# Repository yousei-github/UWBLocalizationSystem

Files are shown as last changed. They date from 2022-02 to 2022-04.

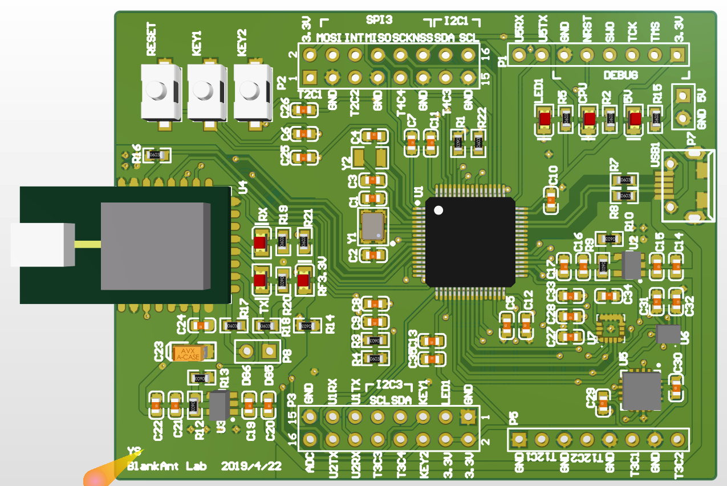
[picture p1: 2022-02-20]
Hardware/picture.png

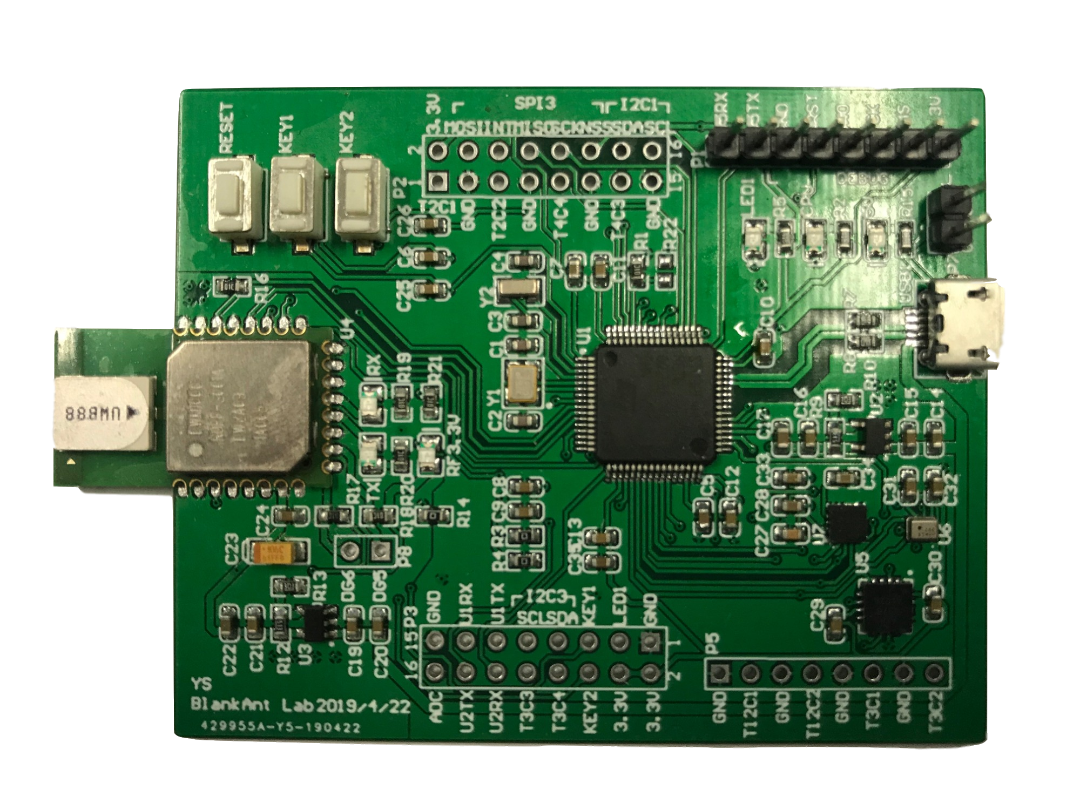
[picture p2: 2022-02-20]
Hardware/real_board.png

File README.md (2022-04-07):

# UWBLocalizationSystem
Designed a localization system based on ultra-wideband technologies (i.e., DWM1000) for the graduation project, which can achieve decimeter-level positioning accuracy using four anchors to navigate the subject (e.g., drone) in the indoor environment. 

## How to compile and execute this project
Please use keil to program this project, such as compile, debug.

Link: https://www.keil.com/

## About the hardware
Please use altium designer to open the hardware design files.

Link: https://www.altium.com/

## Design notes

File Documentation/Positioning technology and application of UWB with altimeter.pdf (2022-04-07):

学号

年级

# 本科毕业论文

# 结合高度计的 UWB 的空间定位技术与应用

专 | 业 | 电子信息工程
姓 | 名 | 杨晟
指导教师 | 李东新 教授

## 评 阅 人

2019 年 5 月

## 中国 南京

## BACHELOR'S DEGREE THESIS OF HOHAI UNIVERSITY

## Positioning technology and application of UWB with altimeter

College | ：College of Computer and Information
Subject | ：Electronic Information Engineering
Name | ：Sheng Yang

Directed by ：Dongxin Li Professor

## NANJING CHINA

# 郑 重 声 明

本人呈交的毕业论文，是在导师的指导下，独立进行研究工作所 取得的成果，所有数据、图片资料真实可靠。尽我所知，除文中已经 注明引用的内容外，本设计（论文）的研究成果不包含他人享有著作 权的内容。对本设计（论文）所涉及的研究工作做出贡献的其他个人 和集体，均已在文中以明确的方式标明。本设计（论文）的知识产权 归属于培养单位。

本人签名： | 日期：

摘 要

无线通信正在成长为我们日常生活的重要组成部分。 卫星通信，蜂窝网络，

无线局域网（WLAN）和无线传感器网络（WSN）是我们每天使用的这些无线技术。

超宽带（UWB）是一种具有大带宽的有前途的技术。 UWB 的这种独特特性使其成为

各种通信，测距和雷达的有吸引力的技术。 本文将重点关注基于 UWB 的精确定位

方面。 由于锚的位置必须手动确认，这有点不方便并且可能带来巨大的错误。 因

此，我使用高度计传感器来帮助定位所有锚点在 z 轴上的位置。 进行实验以比较

使用高度计和不使用高度计的性能

关键词：无线网络；超宽带定位；定位技术；测高计

## ABSTRACT

Wireless communications are growing up to be an essential part of our everyday

lives. Satellite communications, cellular networks, wireless local area networks

(WLANs), and wireless sensor networks (WSNs) are these wireless technologies that

we use every day. Ultra-wideband (UWB) is a promising technology which has large

bandwidths. Such unique trait of UWB turns it into an attractive technology for diverse

communications, ranging, and radar. This paper would focus on the aspect of precise

localization based on UWB. Since the positions of anchors must be confirmed manually,

which is a little inconvenient and may bring enormous error. Therefore, I use the

altimeter sensor to help locate all anchors& position in z-axis. An experiment is

conducted to compare the performance of using altimeter and without it.

Key words: wireless networks；Ultra-wideband；localization； altimeter

## Contents

## Chapter 1 Introduction

1.1 Problem and Research Significance

As wireless devices are growing up to be more and more integrated into

our everyday lives, they are also getting more and more intelligent. In

the book[1]

, it says wireless devices are becoming more context aware, which

is described as the ability of the mobile device to be aware of the its

surrounding environment. Another definition means that if a system is

context aware, it will offer relevant information and services to the user,

which depends on the user’s aims or tasks. Usually those services are based

on the context information such as time, location, temperature, speed,

orientation, biometrics, audio/video recordings, etc.

Among this various information above, location is the main focus in

my paper and is probably the most prevalent factor which depicts a specific

situation. For example in cellular system, location information can be

utilized to Emergency services (911), resource management, and intelligent

logistic systems. In hospitals location of the patients, injured tourists

on mountains, or firefighters inside a building are some examples showing

how location information work in an emergency circumstance. As an office

worker, it would be convenient to find the closest printer while knowing

your position in a wireless network. A customer can receive advertisements

based on location in a supermarket. Such intelligent wireless network

application with location information would make our live much comfortable

and easier.

Real Time Location Systems (RTLS) describes a class of systems that

provide information in real-time about the location of objects, animals,

people or just about anything you care about. The most typical example of

a RTLS is Global Positioning Systems (GPS) developed by the US Department of Defense. It uses the time difference of arrival (TDOA) information from

four or more of 24 satellites around the world to estimate target’s outdoor

position with an accuracy between 1 and 5 m; but it performs poorly for

the indoors environment since walls block GPS signals. Indoor localization

system may need other technology to locate target.

In general, there exists four fundamental signaling scheme that can

be used for a localization system. Radio frequency (RF) maybe the most

commonly used signaling scheme for localization purposes since RF signals

can penetrate through obstacles and propagate to long distances. Cheng

Chen[2]

employed Wi-Fi, odometer and IMU (Inertial measurement unit) fusion

for indoor positioning, and get good results. Infrared signals are low power

consuming and cheap; however, they cannot penetrate through obstructions

(contrast to RF), and are vulnerable against sunlight. Optical signals also

require line-of-sight (LOS) conditions, affected by sunlight, but are low

power consuming. They provide high accuracy and are normally more

appropriate for short ranges (like about 10 m). Liu’s Research[3]

achieved

sub-meter accuracy with fluorescent light communication system. Finally,

an inexpensive signaling scheme is ultrasound signals, which have high

accuracy in the short range. An advantage of acoustic signals is that the

sound travels slowly. Therefore, the localization system doesn’t require

high clocks to timestamp messages, and can be achieved inexpensively in

LOS conditions. With acoustic sensors Qiu[4]

also realize a sub-meter

localization system. However, ultrasound signals cannot work well in

non-line-of-sight (NLOS) scenario.

Ultra-Wideband (UWB) is a RF technology which can achieve

centimeter-level positioning and a range of up to 300 meters. Many

researches have been done using UWB technology, such as Tiemann’s Unmanned

Aerial Vehicle (UAV) navigation[5]

and Shi’s formation flight system[6]

, and

they all get great results. My research would also base on RF signals with

UWB technology to achieve a RTLS.

There are numerous properties of radio waves used to achieve radio

positioning. For instance, time-of-arrival (TOA), time difference of

arrival (TDOA), angle of arrival (AOA), and received signal strength (RSS).

Various methods have been developed over these years to measure radio waves

like time-of-flight (TOF), signal phase, signal strength and angle of

arrival. In most cases, the localization system based on determining the

TOF, which is a similar concept of the TOA, can realize high accuracy. A

fundamental localization method is trilateration. In this case, at least

three serving reference node (RN) are required for two-dimensional (2-D)

localization, and at least four RNs are required for three-dimensional (3-D)

localization. In a localization system, the communication node is often

classified as mobile station and base station. Moreover, mobile station

may equal to tag and base station is often referred to as anchor. In the

case of trilateration, if the absolute location of the anchors is known

in 2D or 3D space then the absolute location of the tags is also known.

Thus, measuring the absolute location of the anchors improperly may bring

enormous error. This paper uses the altimeter sensor to help mitigate all

anchors& position error in z-axis.

### 1.2 Main Design of This System

UWB is an excellent RF technology for high accuracy localization in

short (less than 100 m) to medium (up to 2000 m) distances due to its high

time resolution and inexpensive circuitry. There are already a number of

UWB ranging and positioning devices in the market. Being compliant with

IEEE802.15.4 standard, the Sapphire DART system from Multispectral

Solutions, Inc, Ubisense real-time location system and DecaWave’s DW1000[7]

are all available UWB localization products. An ideal localization system

should fit in all kinds of application, such as accuracy, cost, range, and

complexity. In order to reach these goals, a positioning node is designed with DecaWave’s DWM1000 module[8]

Many RTLS based on UWB technology like Tiemann’s and Shi’s need to

calculate or confirm all anchors’ absolute position manually, which

usually results in each anchor mounts on a regular shelf or framework (like

cuboid and so on). But when employing their system into a more bigger space,

it might become inappropriate as well as deteriorate its accuracy. To

mitigate this drawback, a compensation approach is present and will be

evaluated by taking advantage of altimeter.

## Chapter 2 System Theory Analysis

2.1 Ultra-Wideband

Guglielmo Marconi’s spark gap radio transmitters send UWB signals

across the Atlantic Ocean in 1901, but the precise investigation of UWB

systems was conducted by the studies on impulse response characterization

of microwave networks in the 1960s. Early names of UWB technology include

baseband, carrier-free, non-sinusoidal and impulse. The US Department of

Defense named the term UWB in the late 1980s. A UWB signal is characterized

by its very large bandwidth compared to the conventional narrowband systems,

which means a signal is called UWB if it has an absolute bandwidth of at

least 500 MHz, or its fractional bandwidth is larger than 0.2. The absolute

bandwidth is calculated as the difference between the upper frequency fH

of the −10 dB emission point and the lower frequency fL of the −10 dB

emission point:

| B = fH − fL

(2.1)

which is also called −10 dB bandwidth. Besides, the fractional bandwidth

is defined as

| Bfrac = B fc
(2.2)

where fc is the center frequency and is given by
| fc = fH + fL
| 2

(2.3)

the fractional bandwidth Bfrac in (2.2) can be written as from (2.1) and

(2.3)

| Bfrac = 2(fH − fL ) fH + fL
(2.4)

In accordance with the definition of the US FCC[9]

| , a UWB system with fc that

is larger than 2.5 GHz must have an absolute bandwidth larger than 500

MHz, and then a UWB system with fc which is less than 2.5 GHz must have

a fractional bandwidth larger than 0.2 as showing in Fig. 2.1

Fig. 2. 1 A UWB signal have an absolute bandwidth B ≥ 500 MHz or a fractional bandwidth Bfrac > 0. 2

Because of its large bandwidth, the UWB system has very short duration

waveforms, which usually is several nanoseconds. Ordinarily, the UWB system

transmits ultra-short pulses with a low duty cycle. In this case, the ratio

between the pulse transmission moment and the average time between two

consecutive transmission frames is normally kept small, which commonly

bring an advantage that saving power and energy. Nevertheless, it is

reasonable to keep both low duty cycle instant and continuous transmission

frames.

In a UWB system, numerous pulses are transmitted per information symbol

and information is usually transferred by the positions or the polarities

of the pulses, which was shown in Fig. 2.2. Each pulse occupies in an interval

called a “frame”, and the positions of the pulses in the frames are

determined by a time-hopping (TH) code so that reduce the probability of

collisions with pulses from other UWM system. In Fig. 2.2, three information

have been transmitted, and each bit is composed of two pulses or two frames.

The TH code of the first bit is {2,1}, which implied that in the first frame

the pulse is shifted by 2Tc seconds and the second one is shifted by Tc

seconds, where Tc refers to the chip interval.

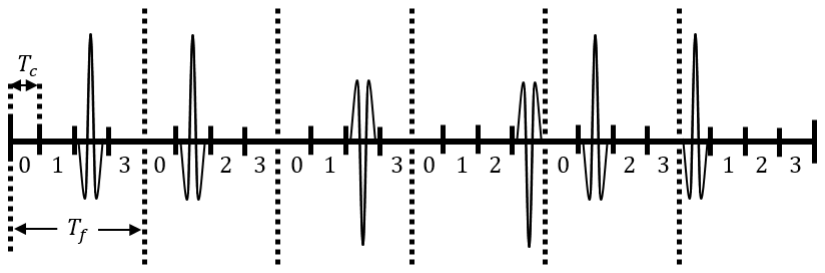
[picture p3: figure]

Fig. 2. 2 A UWB signal whose positions of the pulses in different frames are determined by a TH code, which is {2, 1, 2,3, 1, 0} in this example

2.2 Basic Positioning Methods

There are a variety of different methods of position determination in

RTLS using radio signals but they effectively devolve into two basic types

of scheme:

1) Those based on radio signal strength – commonly referred to as Received

Signal Strength Indication (RSSI/RSS) scheme;

2) Those based on the Time of flight – where the time the radio signal

takes traveling between transmitter and receiver is measured and the

distance can be calculated by using the speed of light. For example, Time

of Arrival, Time Difference of Arrival and Phase difference of Arrival (PDOA)

are three main methods based on Time of flight.

2.2.1 Received signal strength

In this situation, we need to measure the signal strength of the arriving

radio signal at the receiver. Given the power at which the signal was

transmitted from the transmitter, the propagation characteristics of this

radio signal in air and with some a preferred knowledge of the environment,

then it is possible to calculate approximately where the transmission

derived based on how attenuated it is at the receiver.

However, since the RSS usually has a specific (static) distribution

pattern over the localization area, if other objects enter or move in that

area (like people or animals) the distribution pattern would change

perceptibly. This change may greatly worsen the reliability of the

localization system.

On the other hand, such characteristic also has some advantages. In the

field of detection for intrusions or burglaries, positioning needs to be

achieved without performing any communications between the target

(intruder) and the base stations. Using the RSS method and analyzing for

any change in an otherwise static signal pattern, possible intrusions can

be detected.

2.2.2 Time of Arrival

Working on the basis of determining the time it spends for a radio signal

on transmitting from a transmitter to a receiver, the distance between the

transmitter and the receiver can be determined as long as this time is

calculated precisely, given that the speed of propagation of radio waves

in air is known.

Applying the Time of Arrival method to achieve a RTLS, the distance

between the tags and several anchors in known locations must be measured.

In Fig. 2.3 we can see that anchor P1 measures the distance between itself

and the tag B as r1. This locates the tag B on a circle of radius r1 from

the anchor P1. It is the same case that P2 measures the distance with the

tag B as r2 and P3 gets the distance as r3. According to a fundamental

localization method, which is trilateration, calculating the point of

intersection between these three circles could figure out the position of

tag B. The prior condition of this method is the absolute location of the

anchors required to be known.

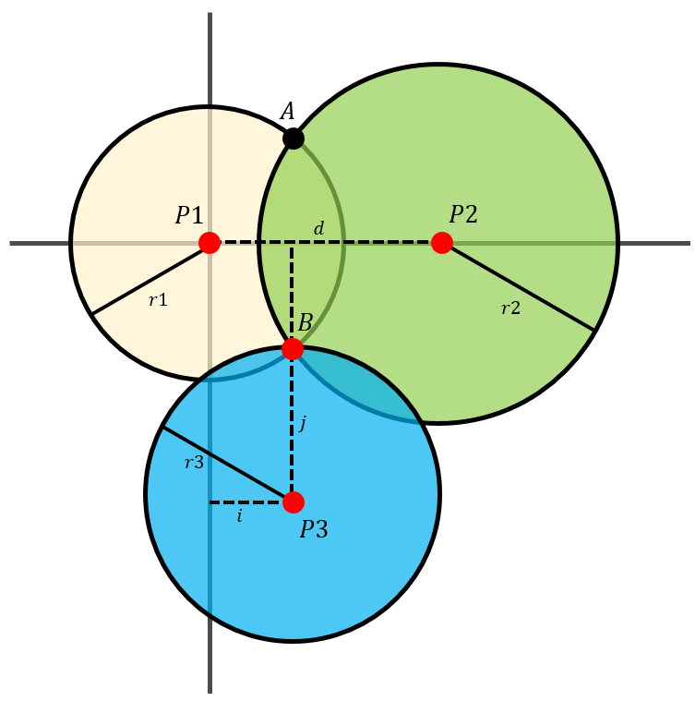
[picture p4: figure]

Fig. 2. 3 Time of Arrival method

2.2.3 Time Difference of Arrival

The similar requirement of TDOA as TOA is that three or more anchors

are utilised in known locations in the environment to locate the positions

of the tags. But each of these anchors is time synchronized to the others.

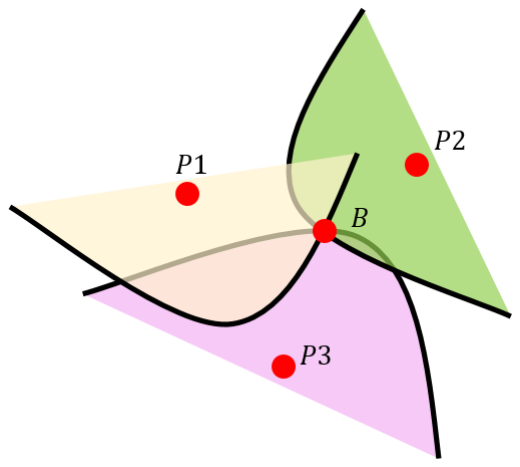
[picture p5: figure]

Fig. 2. 4 Time Difference of Arrival method

As shown in Fig. 2.4 the tag B transmits a message that is received by

all the anchors (P1, P2 and P3). Due to radio wave propagates in air at a

constant speed, relying on the position of the tag B, the message will reach

at some of the anchors before others. Each anchor will record the time of

arrive of this message. Because all three anchors are time synchronized, the difference of the time of arrive among all anchors could estimate the

position of the tag B.

Obviously, the most difficult issue in this method is how to synchronize

all anchors in time. Any error produced in the synchronization process will

directly affect the accuracy of this RTLS. It is because a UWB pulse duration

is usually less than 1 ns, you can think that 1 ns = 30 cm, which means that

the synchronization error must to be controlled within the sub-nanosecond

level to realize high accuracy.

2.2.4 Phase Difference of Arrival

The conception of Phase Difference of Arrival is to calculate the

distance between an anchor and a tag as well as the x, y location of this

tag relative to the corresponding anchor.

This method generally uses an array of antennas in the anchor. The time

of arrive at different antennas will be measured and then the difference

for all TOAs is compared. Showing in Fig. 2.5.

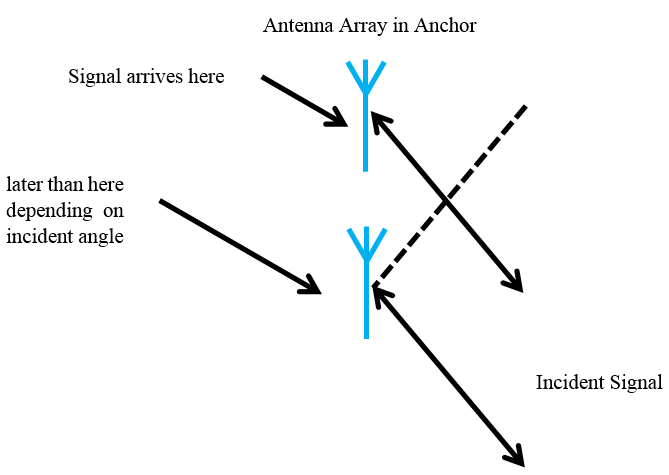
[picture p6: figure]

Fig. 2. 5 Phase Difference of Arrival antenna array

If the tag is coincidentally perpendicular to the antennas in the array,

the incident signal would arrive at all the antennas at the same time, so

there would be no difference in TOA. In most cases, the tag is at some angle

to the array so that the incident signal will arrive at one antenna in the

array first and then next one and so on. It is possible to derive the location

of this tag with precise measurement of Phase Difference of Arrival. On the other hand, increasing the number of antennas per anchor would

apparently adds cost to the RSTL.

2.3 Position Determination Algorithm

Most of common position determination algorithms are based on the

measurement of the TOA of the radio signal, since it can provide the most

accurate position determination. Due to this measurement is the arrival

time at the receiver rather than the Time of Flight, the available

measurement data are pseudo-ranges (range plus an unknown offset), compared

to ranges, there are a number of position determination algorithms used

to process these pseudo-ranges data in a classical localization system

where several fixed anchors are used to determine the location of a tag.

2.3.1 Noniterative Position Determination

Focusing on noniterative position determination methods, the raw

measured data are processed using analytical formulas to calculate the

position of a tag directly. Such algorithms are trilateration, spherical

interpolation (SI), quasi-least squares (QLS), and linear correction

least-squares (LC-LS). Although these methods can definitely get a position

fix, the analytical equations would be computationally intensive. Thus they

might not be appropriate for simple localization system with several nodes

and limited computational capability.

1) Trilateration Position Calculation

In Fig. 2.3 showing a simple example of how to calculate the location of

the tag with the distance measurements from three anchors in a 2D

environment. The tag can communicate with three anchors and its position

is located on each distance circle with the corresponding anchor location

as the center and the distance as the radius. Generally, two distance

circles intersect at two points, which would produce two solutions for the

position estimate of the tag. Therefore, a third anchor is needed to produce

a third distance circle in order to solve this ambiguity of the two solutions.

In general, these circles will not intercross at one point, thus, other

methods are required to calculate the position. There is a straightforward

way that to compute the distance between the third anchor and each of the

two solutions. The two result distances are then compared with the third

distance circle each other. The one which better matches with third anchor

will be the solution, which can be seen that the tag and three anchors cannot

lie in a straight line to calculate a unique position estimate. In Fig. 2.6,

a 3D position estimation is shown.

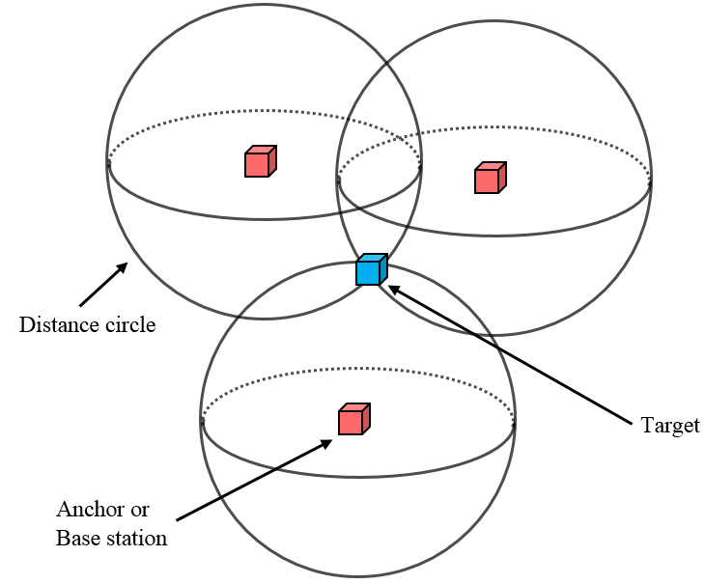
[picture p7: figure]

Fig. 2. 6 Position estimation in 3D environment

Suppose that there are four anchors with known locations given by

(xi
, yi

, zi

), 1 ≤ i ≤ 4, and that the unknown location of the target is denoted

by (x, y, z). The distance measurement equations are defined as

d̂
i = di + εi
i = 1, 2, 3, 4 | (2.5)

where εi is the distance measurement error and

di = √(x − xi
)

2 + (y − yi
)

2 + (z − zi
)
2 | (2.6)

Since there are three unknown location parameters, let us first use three

distance measurements, say d̂

1, d̂

2 and d̂
3, to determine the location. Define

ζi,1 = xi

2 + yi

2 + zi

2 − (x1
2 + y1

2 + z1

2
)

xi,j = xi − xj

yi,j = yi − yj | (2.7)

zi,j = zi − zj

f1,i =

1
2

{(d̂
1

2
− d̂
i

2
) + ζi,1}

Also define

κ1 =

x2,1z3,1 − x3,1z2,1

x3,1y2,1 − x2,1y3,1

κ2 =

x3,1f1,2 − x2,1f1,3

x3,1y2,1 − x2,1y3,1

κ3 =

y3,1z2,1 − y2,1z3,1

x3,1y2,1 − x2,1y3,1

κ4 =

y2,1f1,3 − y3,1f1,2

x3,1y2,1 − x2,1y3,1

(2.8)

Then, with some mathematical manipulations, it can be shown that the

estimate of the z-coordinate of the position is

ẑ=

ℎ2
ℎ1

± √(
ℎ2
ℎ1

)

2
−

ℎ3
ℎ1

(2.9)

Where

ℎ1 = κ1

2 + κ3

2 + 1

ℎ2 = κ1

(y1 − κ2

) + κ3

(x1 − κ4

) + z1

ℎ3 = (x1 − κ4

)

2 + (y1 − κ2
)

2 + z1

2 − d̂
1

2

(2.10)

Accordingly, the estimates of the x-coordinate and y-coordinate can be

obtained as

x̂ = κ3ẑ+ κ4

ŷ = κ1ẑ+ κ2

(2.11)

Clearly, there are two solutions, but only one of them is the desired one.

The ambiguity can be resolved by making use of the measurement at the fourth

anchor. Specifically, the residuals of the two location estimation

solutions are calculated by

v1 = [√(x4 − x̂
(1))
2 + (y4 − ŷ

(1))
2(z4 − ẑ

(1))

2 − d̂

4]

2

v2 = [√(x4 − x̂
(2))
2 + (y4 − ŷ

(2))
2(z4 − ẑ

(2))

2 − d̂

4]

2 | (2.12)

If v1 > v2, then the second solution (x̂

(2)
, ŷ

(2)
, ẑ

(2)
) is chosen. Otherwise,

the first solution (x̂

(1)
, ŷ

(1)
, ẑ

(1)
) is selected. To make the residual-based

judgment as reliable as possible, the fourth anchor should not be on the

same plane formed by the other three anchors.

2) Least-Squares Method based on an Intermediate Variable

When the system is overdetermined, which means the number of independent

equations is greater than the number of unknown parameters, the

Least-Squares (LS) method can be applied to make use of the redundant

measurements to obtain improved location estimates.

Consider a network in which there are N anchors whose locations are

known and denoted by (xi
, yi

, zi

), i = 1, 2, ⋯ , N. The unknown location of the

target is defined as (x, y, z). When a distance measurement is made at each

anchor, there are N measurement equations:

d̂
i = di + vi
i = 1, 2, ⋯ , N | (2.13)

Where

di = √(xi − x)
2 + (yi − y)

2 + (zi − z)

2 | (2.14)

and vi is the measurement error.

Linearization of the distance measurement equations can be realized by

introducing a new variable. Specifically, squaring both sides of (2.13)

produces

−(2xix + 2yiy + 2ziz) + (x

2 + y

2 + z

2

) = (d̂
i − vi)

2
− (xi

2 + yi

2 + zi

2
)
| (2.15)

Then, by defining

R = √x
2 + y

2 + z

2

Ri = √xi
2 + yi 2 + zi
2 | (2.16)
(2.15) becomes

−(2xix + 2yiy + 2ziz) + R

2 = d̂
i

2 − Ri

2 + vi

2 − 2d̂
ivi

(2.17)

which can be written in a compact form as

h = Gθ + v | (2.18)

Where
θ = [x y z R
2]

T

h =
[

d̂
1

2 − R1

2
d̂
2

2 − R2

2
⋮
d̂
N

2 − RN

2

]

G = [

−2x1 | −2y1
−2x2 | −2y2
−2z1 | 1
−2z2 | 1
⋮ | ⋮
−2xN | −2yN
⋮ | ⋮
−2zN | 1

]

v = [−v1

2 + 2d̂
1v1 −v2

2 + 2d̂
2v2 ⋯ −vN

2 + 2d̂
NvN

]

T

(2.19)

The LS solution of (2.18) is

θ̂ = (G
TWG)

−1G

TWh | (2.20)

where W = cov⁻¹
(v) is the weighting matrix which is set to be the inverse

of the covariance matrix of v for Gaussian noise. In the case of unknown

statistics of the error vector v, W may be set at a diagonal matrix with

the SNRs determined by receivers as the diagonal elements, or simply set

at an identity matrix.

2.3.2 Iterative Position Determination

In this case, iterative methods are used to solve the nonlinear

equations which describe the position determination problem. For example,

there are Taylor series least squares (TS-LS) method, the iterative

optimization method and the maximum likelihood (ML) method and Kalman

filter iterative method. Commonly, these iterative methods need an initial

‘guess’ of the position, but in some situation, especially when large

measurement errors are present these algorithms may not converge.

Nevertheless, in the localization system while continuous periodic updates

are running, the previous position can be used as the initial position, which normally approaches to a rapid convergence of position determination

without large computation contrasting to the noniterative methods.

2.4 Indoor Height Determination

In order to measure the height between the target object and reference

plain, there are several kinds of commercial sensors could be used. They

may be classified as three types: laser, ultrasonic and barometer. The first

two types both can achieve high accuracy and stability, but they all need

the line of sight environment, which means that if height measurement is

required, these sensors must be installed on the bottom of the target object

and should be toward to the reference plain (like ground), and the line

between them cannot be block by other obstacles. As a result, it is

inconvenient to utilize the laser or ultrasonic sensors to measure height.

However, the barometer (or altimeter) can determine the height without the

line of sight requirement.

2.4.1 Atmospheric pressure measurement

The atmospheric pressure is the weight exerted by the overhead

atmosphere on a unit area of surface. It can be measured with a mercury

barometer, as shown in Fig. 2.7.

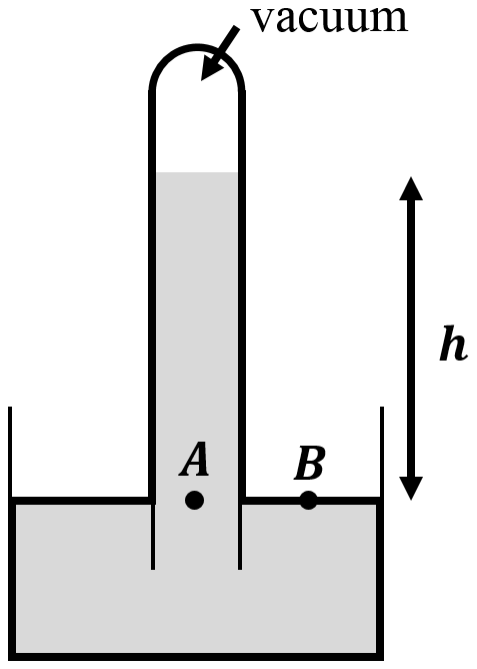
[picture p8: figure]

Fig. 2. 7 Mercury barometer

There is a long glass tube that is full of mercury inverted over a pool

of mercury. According to some physical knowledge, it is well known that

the pressure PA at point A is equal to the pressure PB at point B and the

equilibrium equation can be represented as:

PA = ρHg gℎ | (2.21)
where ρHg = 13.6 g cm⁻³ is the density of mercury and g = 9.8 m s | −2 is the

acceleration of gravity. The mean value of ℎ measured at sea level is

76.0 cm , hence, the corresponding atmospheric pressure is 1.013 ×

10⁵ kg m⁻¹
s

−2 ; 1 Pa = 1 kg m⁻¹
s

−2 . There are also some customary

pressure such as the atmosphere (atm) (1 atm = 1.013 × 10⁵ Pa), the bar (b)

(1 b = 1 × 10⁵ Pa), the millibar (mb) (1 mb = 100 Pa), the torr 1 torr =

1 mm Hg = 134 Pa ) and the hectoPascals (hPa). The mean atmospheric

pressure at sea level is given equivalently as P = 1.013 × 10⁵ Pa =

1013 hPa = 1013 mb = 1 atm = 760 torr.

2.4.2 Barometric law

Here the vertical profile of pressure will be explained. An elementary slab

of atmosphere at altitude z with thickness dz, horizontal area A is shown

in Fig. 2.8:

Fig. 2. 8 Vertical forces acting on an elementary slab of atmosphere

The outer atmosphere exerts an upward pressure force P(z)A on the bottom

of the slab and a downward pressure force P(z + dz)A on the top of the slab.

So the resultant force on the black net is (P(z) − P(z + dz))A, which is

also called the pressure-gradient force. Since P(z) > P(z + dz) , the pressure-gradient force is directed upwards. In order to become equilibrium

for the slab, its weight should equal to the pressure-gradient force:

ρagAdz = (P(z) − P(z + dz))A

(2.22)

rearranging and dP/dz can be seen:
dP
dz =

P(z + dz) − P(z)
dz | = −ρag

(2.23)

since the ideal gas law is

ρa =

PMa
RT

(2.24)

where Ma is the molecular weight of air (common value is 28.96 ×

10⁻³ kg mol⁻¹ ), R = 8.31 J mol⁻¹ K

−1 is the gas constant and T is the

temperature (the unit usually is K ). Substituting (2.24) into (2.23)

produce:
dP
P

= −

Mag
RT dz | (2.25)

Now if only the constant T with altitude situation is considered, using

integration can yield:

P(z) = P(0) exp (−

Mag
RT z)
(2.26)

equation (2.26) is called the barometric law[10]

. Commonly a definition of

the scale height H is used for the atmosphere:

H =

RT
Mag

(2.27)

producing a compact form for the barometric law:

P(z) = P(0)e

−

z
H

(2.28)

However, the temperature will change according to altitude. The

International Civil Aviation Organization (ICAO) defined the International

Standard Atmosphere[11]

, which model the temperature variation as shown in

Fig. 2.9:

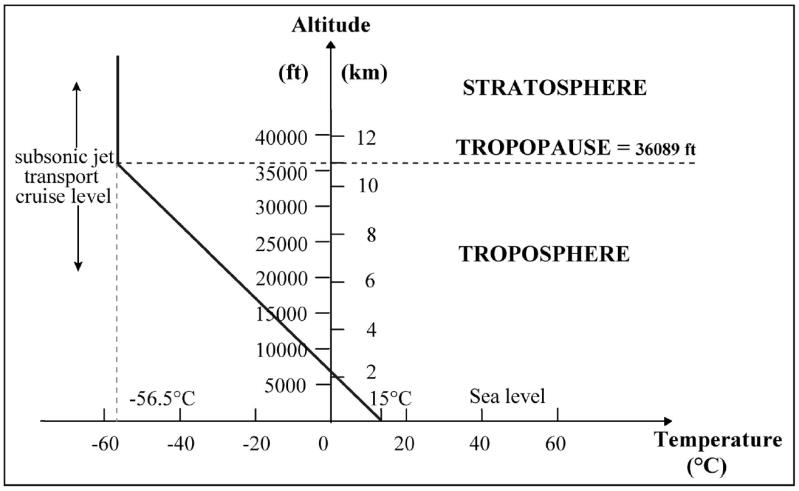
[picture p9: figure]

Fig. 2. 9 International Standard Atmosphere temperature variation

For example, in the troposphere (from 0 m to 11,000 m) the temperature

decreases with altitude at a constant rate of −6.5℃/1000m (−1.98℃/

1000ft). So the ISA model presents the following characteristics within the

troposphere:

T = T0 − 6.5

ℎ − ℎ0
1000

(2.29)

where the unit of T and T0 is K, and ℎ and ℎ0 is in meters, and T0 or ℎ0

could be the corresponding value at sea level.

Now replacing (2.29) into (2.25) and integrating both sides:
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
T0 − 0.0065(ℎ − ℎ0

)

ℎ

ℎ0=0

(2.30)

performing the above integration, a simple formula can be produced:

p = p0 (1 − 0.0065

ℎ − ℎ0
T0

)

5.2561 | (2.31)

2.4.3 Height measurement

It is well known that based on above law, in aircrafts altimeters use

barometer to measure the air pressure and use this information to produce

the altitude. Due to the real atmosphere never keep constant at any specific

place or time, height measurement also need local air pressure information

from such meteorological stations, airports or control towers as reference points, and these reference stations should not be too far away from the

interesting atmosphere environment[12]

To calculate height, the (2.31) of barometric law needs to be inverted as:

ℎ = ℎ0 +

T0
0.0065 −

T0
0.0065 (

p
p0

)

1
5.2561

(2.32)

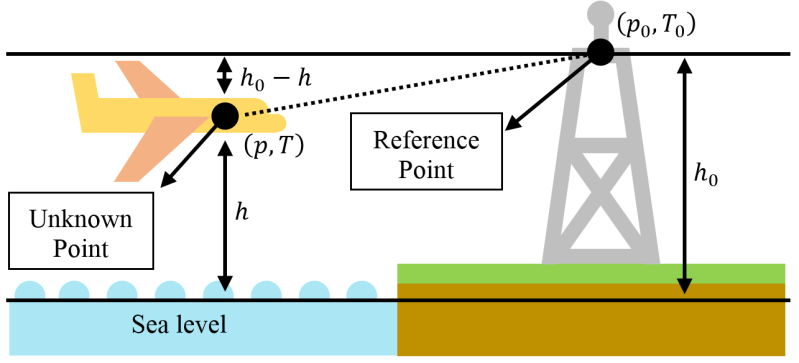
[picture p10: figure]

Fig. 2. 10 Height measurement from air pressure

As shown in Fig. 2.10, or referring to this paper[13]

, if the status (p0
, T0

, ℎ0

)
of the reference point is known and air pressure (p) is also known, it is possible to calculate the height (ℎ) from equation (2.32) and relative height (ℎ − ℎ0

).

## Chapter 3 System Hardware Design

3.1 UWB localization module

The hardware design of the UWB localization module is presented in this

chapter. As depicted in Fig. 2.11, the whole module layout can be divided

as six blocks: main controller, power, UWB module, sensors, button and led

circuitry.

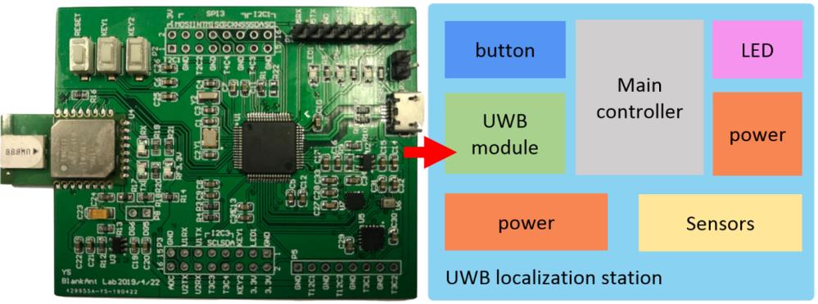
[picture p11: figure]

Fig. 2. 11 UWB localization module layout

3.1.1 Main controller

Considering the calculation performance, volume size and cost, the

STM32F446xx microcontroller of the st company[14]

has been chosen as the main

controller | for | the | UWB | localization | module. | The | STM32F446xx

microcontroller is based on the ARM 32-bit Cortex-M4 CPU and its frequency

can be up to 180 MHz with 225 DMIPS (Dhrystone Million Instructions executed

Per Second). It also has a 512 kB flash memory and a 128 kB SRAM, which

is suitable for its application.

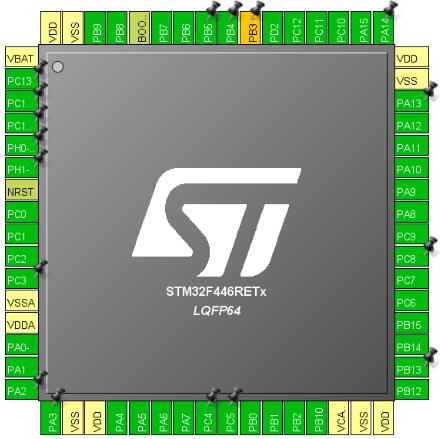
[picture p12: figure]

Fig. 2. 12 STM32F446xx microcontroller

3.1.2 Power design

According to the dw1000 hardware design guide[15]

, which could be as a

reference sheet for the UWB module, two kinds of power circuitry has been

designed and they are digital and RF management circuit separately in order

to keep each of their noise away from itself. This power architecture can

make sure that the UWB module and all sensors work steadily.

Fig. 2. 13 Power design

3.1.3 UWB module

There are various UWB products which are compliant with the IEEE802.15.4

standard. The DWM1000 module of the decaWave company is selected as the

UWB module. It has many advantages for this research, such as high precision

(about 10 cm indoors), allowing high data rate (up to 6.8 Mb/s), good

communication range (maximum is 300 m), low power consumption (max working

current is about 250 mA) and so on. A key trait is that its integrated

antenna allows simple product implementation, therefore there is no RF

design requirement for the research.

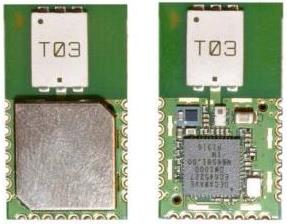
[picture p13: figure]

Fig. 2. 14 DWM1000 module

3.1.4 Altimeter

As for the altimeter, the SPL06-001 of the GoerTek company is the sensor for the research. The SPL06-001 is a digital barometric air pressure sensor

with high accuracy (± 0.006 hPa or ± 5 cm) and low power consumption (about

60 μA). Its pressure operating range is between maximum 1200 hPa and

minimum 300 hPa and temperature range is from 85 ℃ to − 40℃ which is

appropriate for indoor environment.

Fig. 2. 15 SPL06-001 barometer

## Chapter 4 System Software Design

4.1 UWB localization system

The software design of the UWB localization module is presented in this

chapter. Its whole structure is shown in Fig. 2.12 where four main software

blocks has been drawn. They are positioning algorithm, distance measurement,

height measurement and UWB communication framework software blocks.

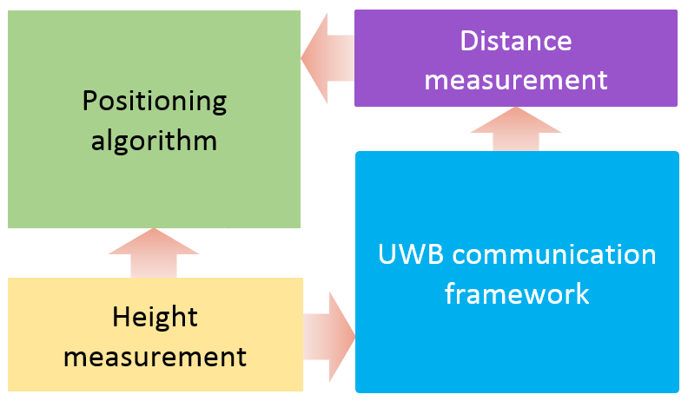
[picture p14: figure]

Fig. 2. 16 Software structure

4.1.1 Distance measurement method

This system employs two-way ranging exchange (TWR) to measure distance

between the tag and each anchor, which is the unsynchronized positioning

method in TOA. In this scene, the tag needs to communicate individually

with each of all anchors and then each anchor will calculate the time of

flight of the transmission from the tag. A simplified scheme of TWR is

depicted in Fig. 2.13 and can be described as below:

1) The tag transmits a message to an anchor and records the time t1 when

the message is emitted from its antenna;

2) The anchor receives the message and marks the time of arrive t2;
3) The anchor sends back a reply and record the time t3;
4) The tag receives the final message and marks the final time of arrive

t4;

5) Then the tag can calculate the distance between them since the speed

of transmission is known.

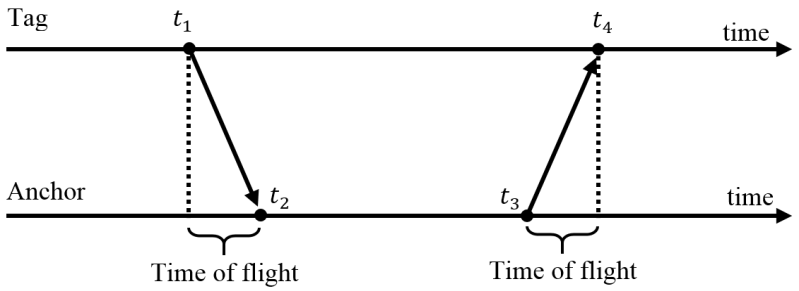
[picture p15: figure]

Therefore, according to the formula:

Ttime of flight =

t2 − t1 + t4 − t3
2

(2.33)

The distance between the tag and anchor can be solved. However, there are

various physical effects such as clock drift which this simple scheme of

TWR may be suffered greatly. Other more advanced scheme such as double-sided

two-way ranging (DS-TWR) could use to correct these errors. A simplified

double-sided two-way ranging is as shown in Fig. 2.13.

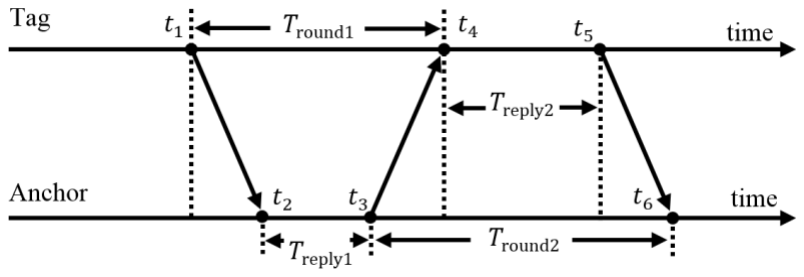
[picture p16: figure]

The resultant time of flight may be calculated by using the expression:

Ttime of flight =

(Tround1 × Tround2 − Treply1 × Treply2)

(Tround1 + Tround2 + Treply1 + Treply2)

(2.34)

In this method, the classic clock drift error is in the picosecond range

even with 20 ppm crystals, and the major source of error is the precision

of determining the arrival time of the messages at each of the receivers

rather than the clock drift error.

4.1.2 UWB module communication framework

Using this UWB localization system, each of all five UWB localization

modules has two mission. They are update height measurement and distance

measurement respectively. As shown in Fig. 2.14, the first mission is that

one of four anchors will act as a reference node to offer its own height,

and remained anchors as well as the tag utilize this measurement as the reference point to produce their own altitude. After finishing updating

height measurement task, the tag would initiate the TWR exchange program

to measure all distances between each four anchors and itself.

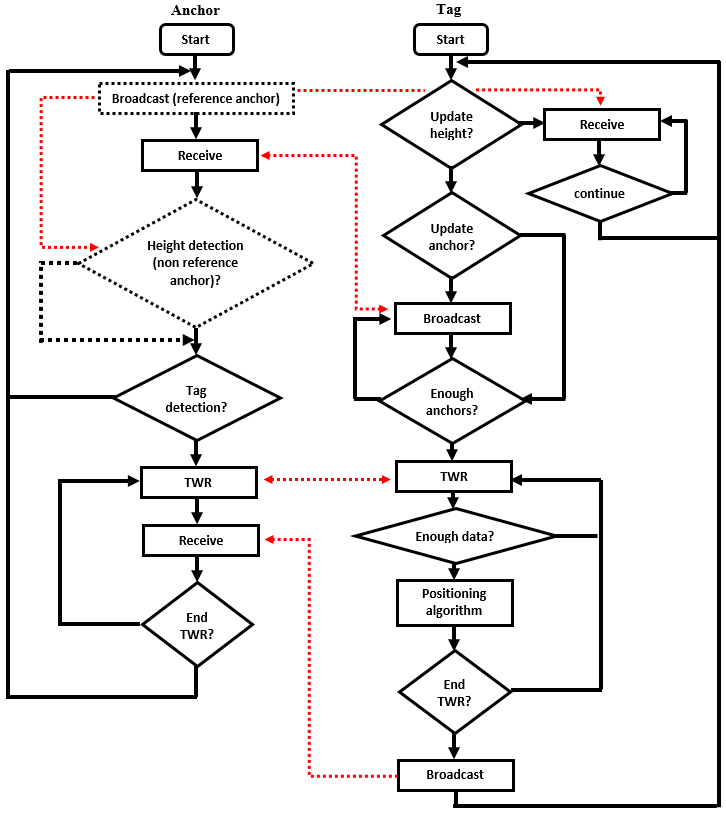
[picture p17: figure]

Fig. 2. 17 UWB module communication framework

1) Update height measurement task

In the first mission, one anchor operates as a reference point. Others

units act as the receiver. The reference anchor broadcast the height

measurement message and remainders wait to receive this message, which can

be seen in Fig. 2.15. As for this research, all four anchors are named as

Y0, Y1, Y2, Y3 and the tag is called the S0. Then the Y0 anchor is chosen for

the reference point.

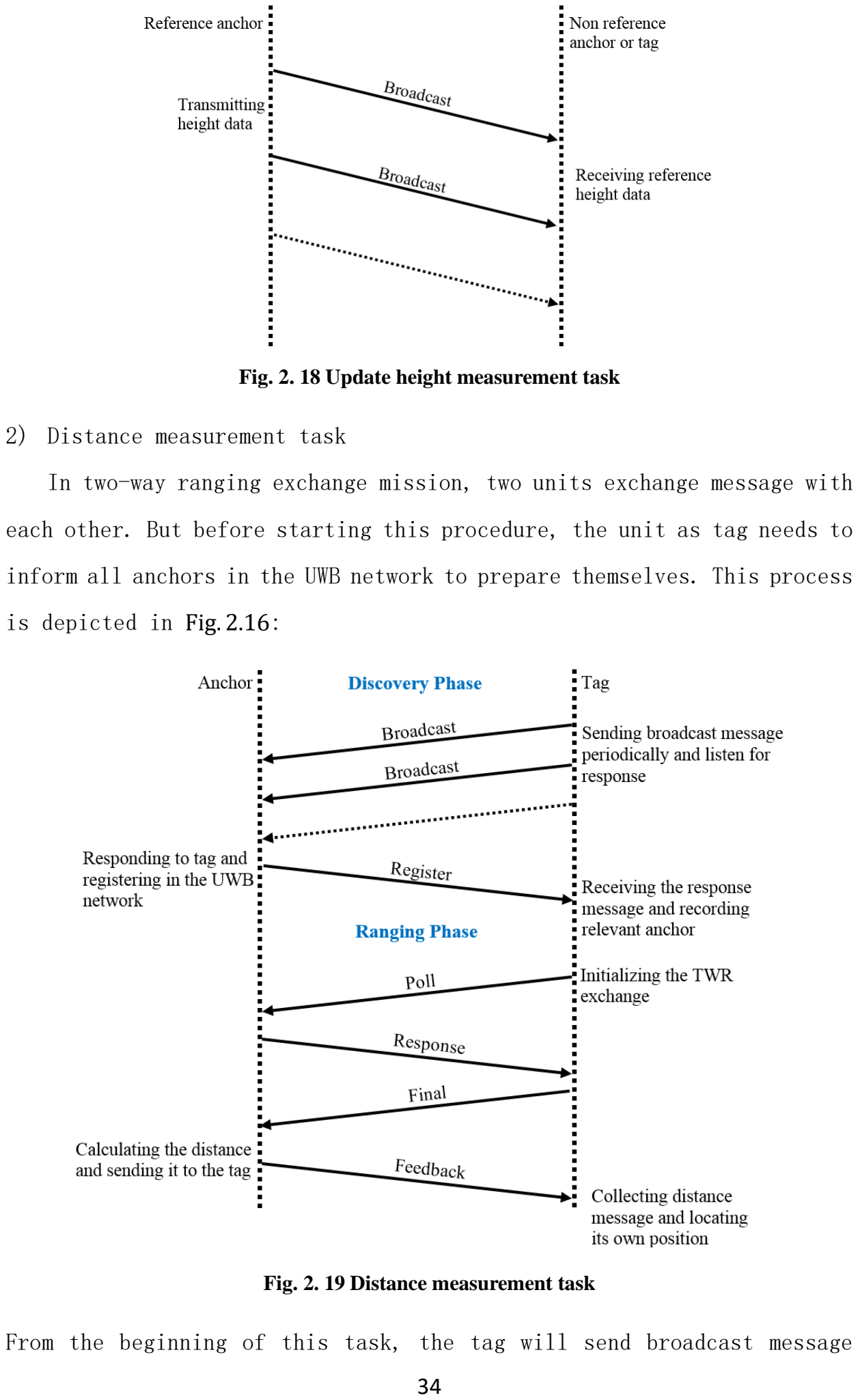
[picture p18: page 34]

Fig. 2. 18 Update height measurement task

2) Distance measurement task

In two-way ranging exchange mission, two units exchange message with

each other. But before starting this procedure, the unit as tag needs to

inform all anchors in the UWB network to prepare themselves. This process

is depicted in Fig. 2.16:

Fig. 2. 19 Distance measurement task

From the beginning of this task, the tag will send broadcast message periodically and then listen for response from anchors, which is to make

sure there would have enough data to calculate its position. After receiving

the response of the anchor and obtaining enough number of registered anchors

in the UWB network, the tag should initialize and perform the two-way

ranging exchange until it acquires all the ranging data.

4.1.3 Altimeter height calculation

The barometer is the altimeter to measure the vertical distance between

the anchors and reference plain. In general, many researches have been

conducted to apply the barometer in indoor or outdoor environment. However,

since the ambient air pressure measured are affected by the variation of

surrounding temperature, ventilation and so on, the performance of the

barometer usually is not ideal. Thus, the main error source of the barometer

height must be researched. For most cases, it is composed of the bias term,

drift term and noise term. The bias term, or initial sensor bias, normally

is constant and could be removed by calibration. The drift term which is

caused by the fluctuation of ambient temperature, ventilation and other

uncertain factors. The noise term is the measurement noise of the barometric

height. Hence, the height measurement of barometer can be represented as

following:

P̂
barometer = Psea + ∆Pbarometer + Pbias + Pdrift + nbarometer | (2.35)

where P̂
barometer is the measurement data from the barometer, and ∆Pbarometer

refers to the difference of the true pressure of current position of the

barometer | and | the | pressure | in | the | sea | level. | In | addition,

Pbias, Pdrift and nbarometer are individually the bias term, drift term and noise

term talked above.

With the purpose of minimizing error from height measurement, the

calibration algorithm and a second barometer as a reference point will be

exercised. The solution is adjusting the barometer before using it for

positioning as below:

1. Place the barometer and the reference one on the same horizontal plain

and calculate the pressure offset ( ∆P̂
bias

0 = P̂
barometer

0 − P̂
reference

0 ) between

these two units;

2. Move these barometers to their targeted position and calculate their
absolute | height | ℎbarometer = ℎ0 +

T0
0.0065

−

T0

0.0065 (
P̂

barometer−∆P̂
bias

0

p0

)

1
5.2561
and

ℎreference = ℎ0 +

T0
0.0065

−

T0
0.0065 (

P̂
reference
p0

)

1
5.2561
;
3. Compute the relative height ℎrelative = ℎbarometer − ℎreference.

The reference point should not be too far away from the indoor environment

where the barometer is installed since above formula requires a similar

atmosphere.

4.1.4 Positioning algorithm design

Based on the trilateration positioning algorithm, the UWB localization system

can locate the position of tag with the cooperation of four anchors. Working on the

UWB module communication framework, the tag is able to exchange the ranging or

broadcast messages orderly with all four anchors. As long as collecting enough ranging

data, the tag will input these data to the trilateration positioning algorithm to

locate its own position. The flow chart about it is drawn in Fig. 2.17.

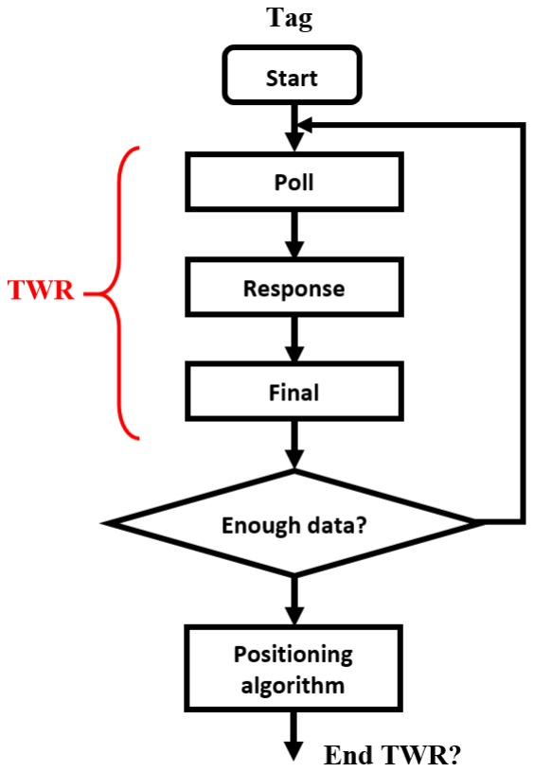
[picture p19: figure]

Fig. 2. 20 Positioning algorithm flow chart

## Chapter 5 Experiment and Data Analysis

To evaluate the performance of the UWB localization system, the

experiment was designed in this chapter. The four anchors were mounted on

the vertex of the square area which can be seen in Fig. 2.18 with 4 m long

and 3 m width, and three of them were lie on the ground while another was

installed on the top surface of chair whose vertical distance to ground

is 2.3 m. To construct Cartesian coordinate system, the anchor A1 is the

original point and the edge of A1 and A2 acts as x axis, while the y axis

is the edge which is the projection to the ground between A1 and A4. The

z axis is parallel to the height of A4 from the bottom to top and goes

through the original point.

The tag was connected to a data transmission module with serial port

so it can send its position information to the host computer. Moreover,

in order to keep the UWB ranging protocol more efficient to increase

positioning accuracy and real-time ability, each UWB localization module

transmit common messages rather than ranging messages via Zigbee modules,

which is really mature and easy to use because there are no requirement

to program the complicated protocol stack or build a multi-hop mesh network.

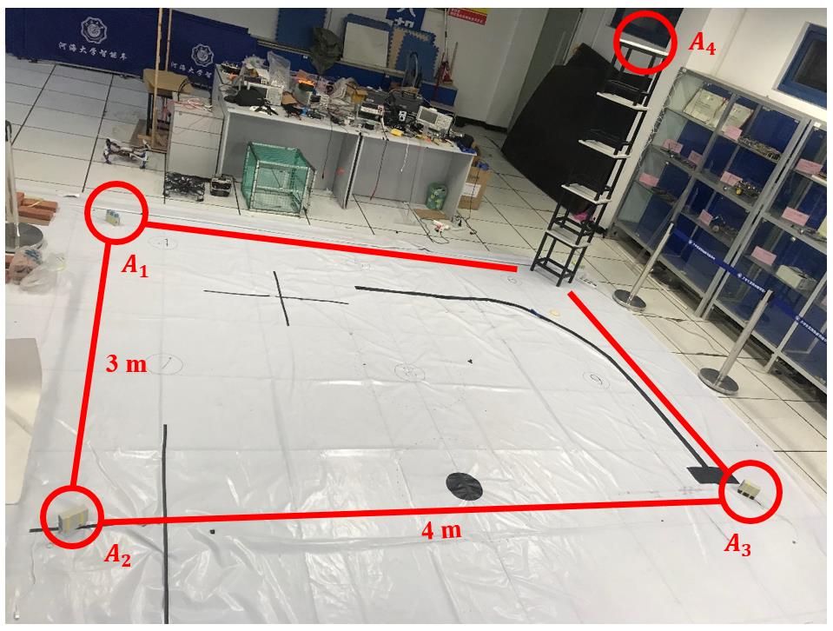
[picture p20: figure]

Fig. 2. 21 Photo of UWB localization experiment

This experiment can mainly divide to two aspect: with altimeter and

without altimeter. The test environment is set in our laboratory and the

static localization with a constant position was analyzed firstly. Then,

the dynamic localization in the x, y axis and z axis scenarios were evaluated

separately. In the x, y axis scenario three types of trajectory movement had

been applied and recorded using rectangular, diagonal as well as triangle

shape, as shown in Fig. 2.19.

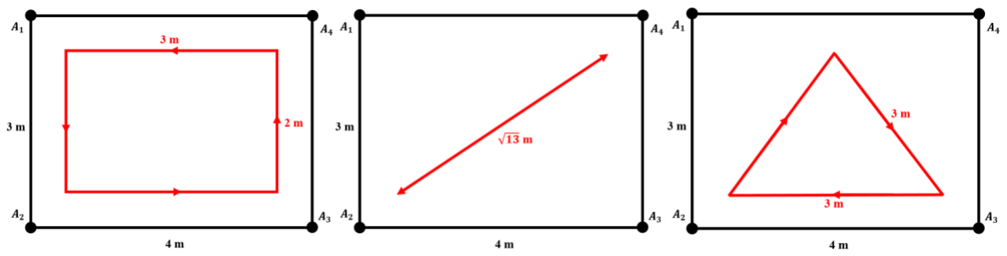
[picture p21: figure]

Fig. 2. 22 Three types of trajectory movement

Furthermore, the ranging data distribution graph based on time was also

depicted in this case. However, since the limit of the evaluation tool,

only a distribution graph established on time was performed in z axis

scenario.

5.1 Positioning test without the altimeters

For the static situation, the tag was placed on the top surface of the

chair. The ground-true position of it is (1.5 m, 2 m, 0.6 m) and data analysis

is drawn as below:

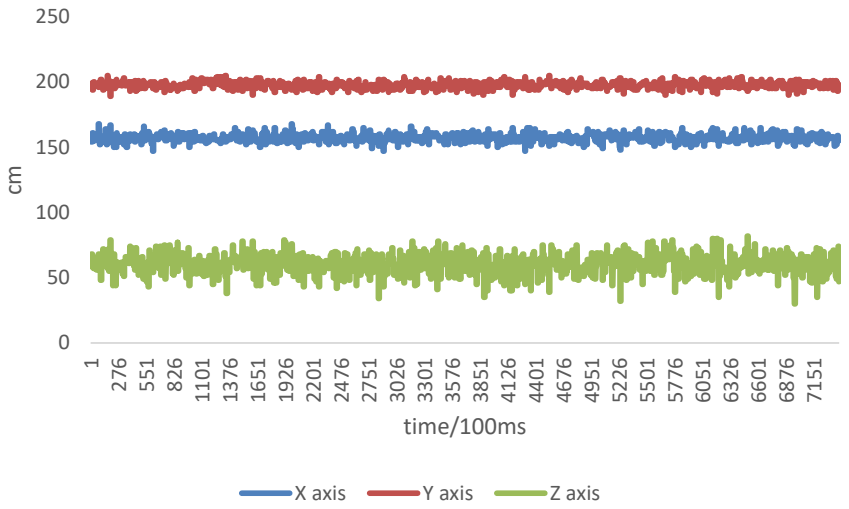
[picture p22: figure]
time/100ms; X axis; Y axis; Z axis

Fig. 2. 23 Ranging data distribution graph in static case

Table 1 Standard deviation in static case

Axis | Time phase | Standard deviation
X | 1-7151 | 3.404
Y | 1-7151 | 3.021
Z | 1-7151 | 8.176

On the other hand, in the first scene of the dynamic situation the tag

moved along the four rims of the red. The length of long side of the

rectangular is 3 m and the width is 2 m. When moving on the red rectangular

the tag was keeping constant height. Each of ranging data distribution graph

about x, y axis is depicted below as well as their deviation was also analyzed.

The second scene is a back and forth diagonal trajectory which was carried

out and recorded similarly as well as the third scene about a regular

triangle trajectory.

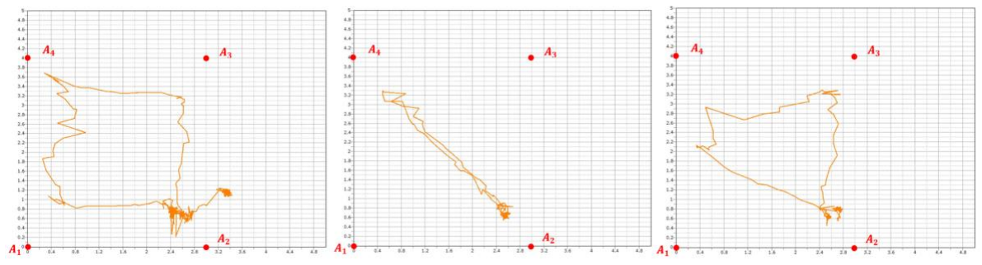
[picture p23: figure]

Fig. 2. 24 The trajectory of the rectangular, diagonal and triangular

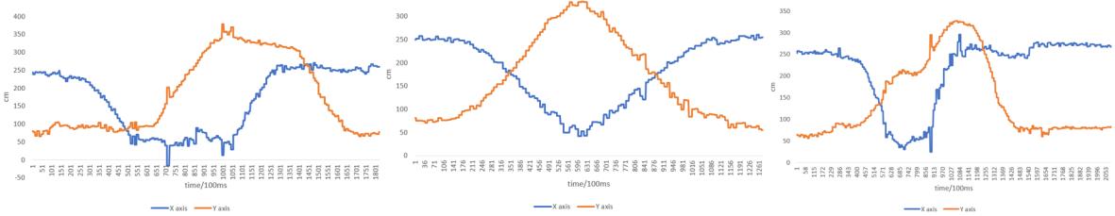
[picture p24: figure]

Fig. 2. 25 Ranging data distribution graph in x, y axis

In other respects, the evaluation of dynamic accuracy of z axis was

executed here. The tag was mounted on the top surface of the chair with

0.6 m fixed height and moving randomly. Relevant data analysis is presented

in Fig. 2.26 with 30.5 standard deviation. The result why the UWB

localization system produce zero solution in this case may be because of

the error of each UWB module, which also create a blind area above the ground

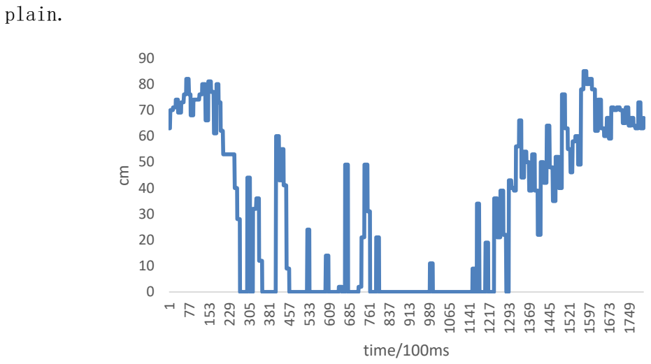
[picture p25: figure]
plain.; time/100ms

Fig. 2. 26 Ranging data distribution graph in z axis

5.2 Positioning test with the altimeters

In here those two scenarios (static and dynamic) is also discussed but

the barometer was utilized to determine the position of z axis of each

anchors. In the purpose of simplifying and minimizing the error of manual

installation, the experiment data was recorded and shown as below:

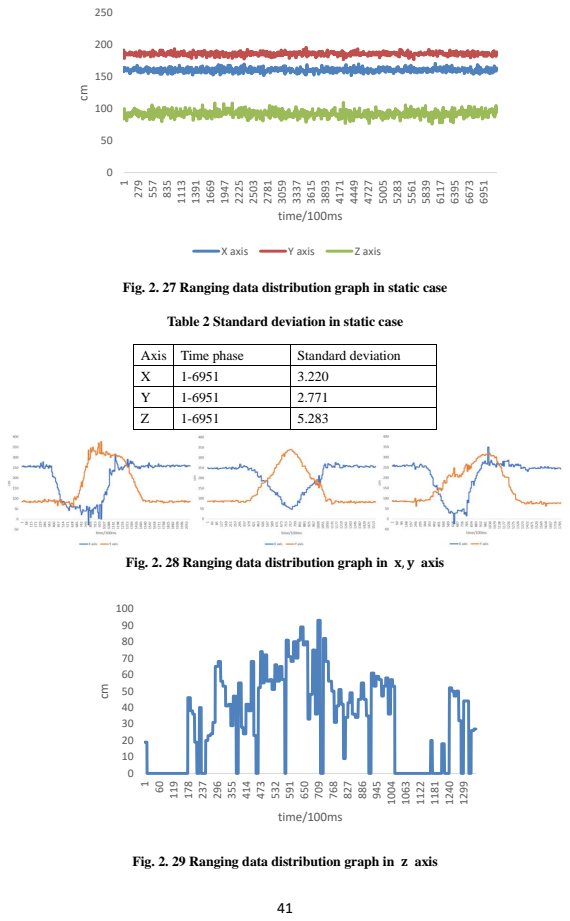
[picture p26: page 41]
time/100ms; X axis; Y axis; Z axis

Fig. 2. 27 Ranging data distribution graph in static case

Table 2 Standard deviation in static case

Axis | Time phase | Standard deviation
X | 1-6951 | 3.220
Y | 1-6951 | 2.771
Z | 1-6951 | 5.283

Fig. 2. 28 Ranging data distribution graph in x, y axis

Fig. 2. 29 Ranging data distribution graph in z axis

By analyzing these ranging data, the standard deviation in static

scenario was improved, but in dynamic scenario the magnitude of burr noise

was increased. Moreover, the disaster in z axis of the dynamic situation

does not get better.

## Chapter 6 Conclusion

In this paper, an UWB localization system with altimeter was introduced.

Though by using the barometer to calculate the height of each of four anchors,

which may simplify the procedure of installation of the base station and

minimize the error caused by manual operation, the noise of ranging data

is enlarged by the noise of the barometer. Therefore, the proposed method

cannot be utilized in real environment.

In order to optimize the performance of the UWB localization system,

there are still a lot of improvement needed to be research, such as more

advanced algorithm, multiple sensors fusion and so on, and more experiments

need to be carry out.

## References

[1] Sahinoglu, Zafer. Ultra-wideband positioning systems. Cambridge university press, 2008.
[2] Chen, Cheng, et al. "Low cost IMU based indoor mobile robot navigation
with | the | assist | of | odometry | and | Wi-Fi | using | dynamic
constraints." Proceedings of the 2012 IEEE/ION Position, Location and Navigation Symposium. IEEE, 2012.
[3] Liu, Xiaohan, Hideo Makino, and Kenichi Mase. "Improved indoor location estimation using fluorescent light communication system with a nine-channel receiver." IEICE transactions on communications 93.11 (2010): 2936-2944.
[4] Qiu, Chen, and Matt W. Mutka. "Silent whistle: Effective indoor positioning with assistance from acoustic sensing on smartphones." A World of Wireless, Mobile and Multimedia Networks (WoWMoM), 2017 IEEE 18th International Symposium on. IEEE, 2017.
[5] Tiemann, Janis, Florian Schweikowski, and Christian Wietfeld. "Design of an UWB indoor-positioning system for UAV navigation in GNSS-denied environments." Indoor Positioning and Indoor Navigation (IPIN), 2015 International Conference on. IEEE, 2015.
[6] Shi, Zhiyuan, et al. "A Nano-Quadcopter Formation Flight System Based on UWB Indoor Positioning Technology." 2018 13th International Conference on Computer Science ‘ Education (ICCSE). IEEE, 2018.
[7] Decawave DW1000 Product Brief. [Online]. Available: www.decawave.com
[8] Decawave | DWM1000 | Product | Information: | [Online]. | Available:
www.decawave.com
[9] Federal Communications Commission, First Report and Order 02-48, Feb. 2002.
[10] Jacob, Daniel J. Introduction to atmospheric chemistry. Princeton University Press, 1999.
[11] Cavcar, Mustafa. "The international standard atmosphere (isa)." Anadolu University, Turkey 30 (2000): 9.
[12] Li, Binghao, Bruce Harvey, and Thomas Gallagher. "Using barometers to determine the height for indoor positioning." International Conference on Indoor Positioning and Indoor Navigation. IEEE, 2013.
[13] Liu, Guangwen, et al. "Beyond horizontal location context: measuring elevation using smartphone's barometer." Proceedings of the 2014 ACM International Joint Conference on Pervasive and Ubiquitous Computing: Adjunct Publication. ACM, 2014.
[14] STMicroelectronics web site. [Online]. Available: www.st.com
[15] Decawave DW1000 hardware design guide. [Online]. Available: www.decawave.com

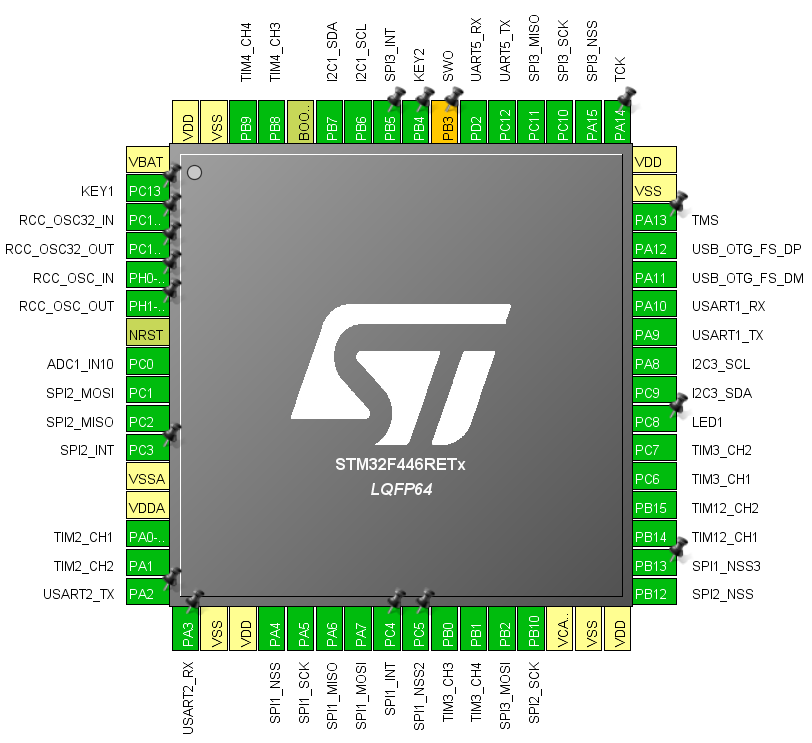
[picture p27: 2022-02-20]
Hardware/Pin_config.png

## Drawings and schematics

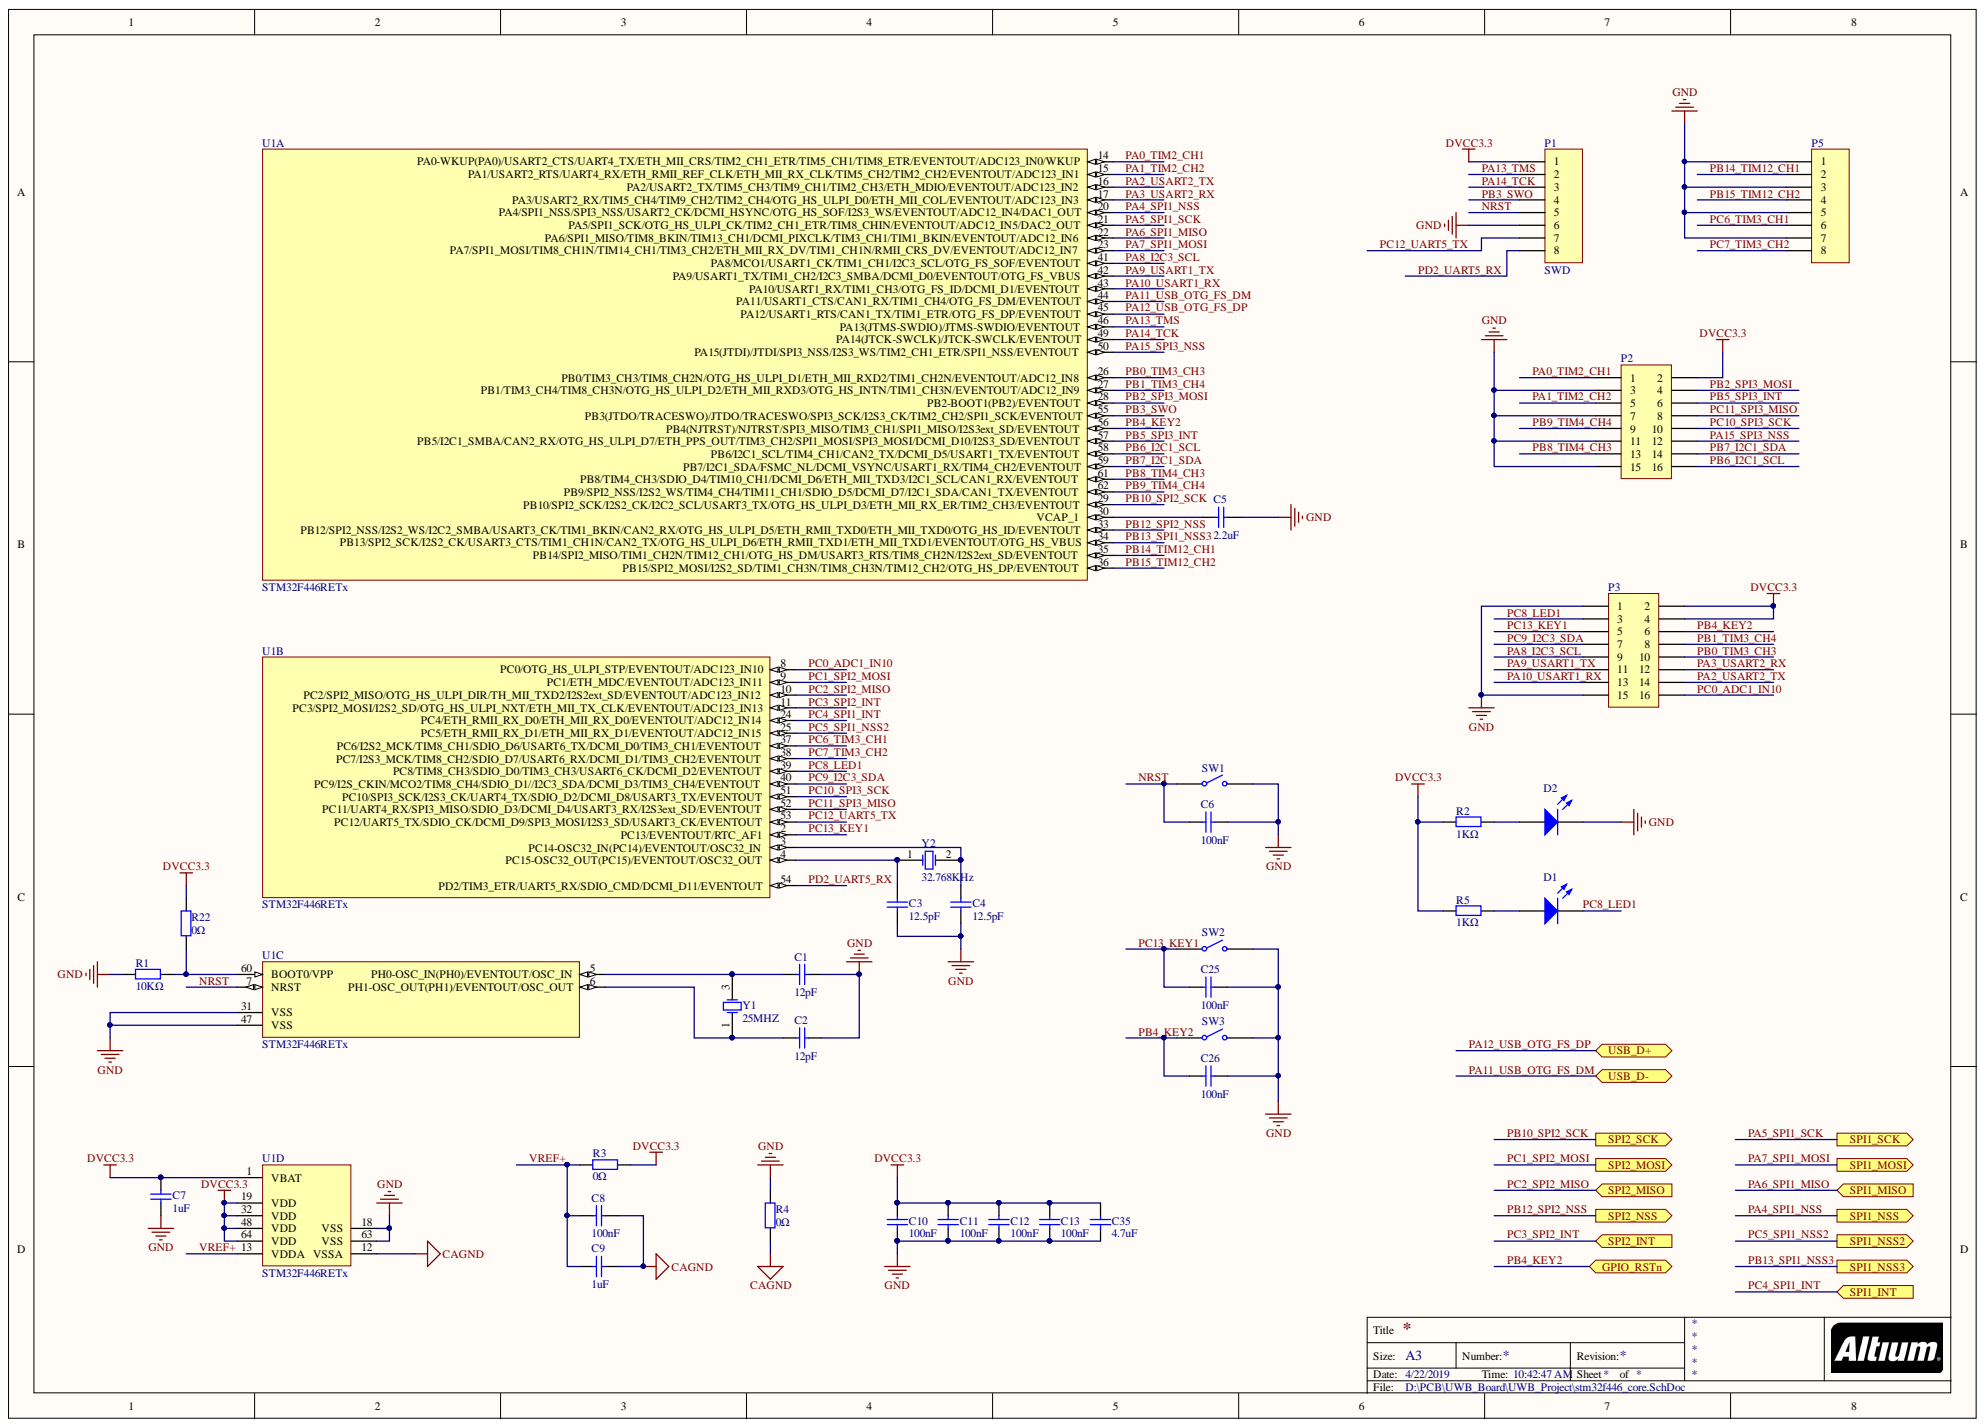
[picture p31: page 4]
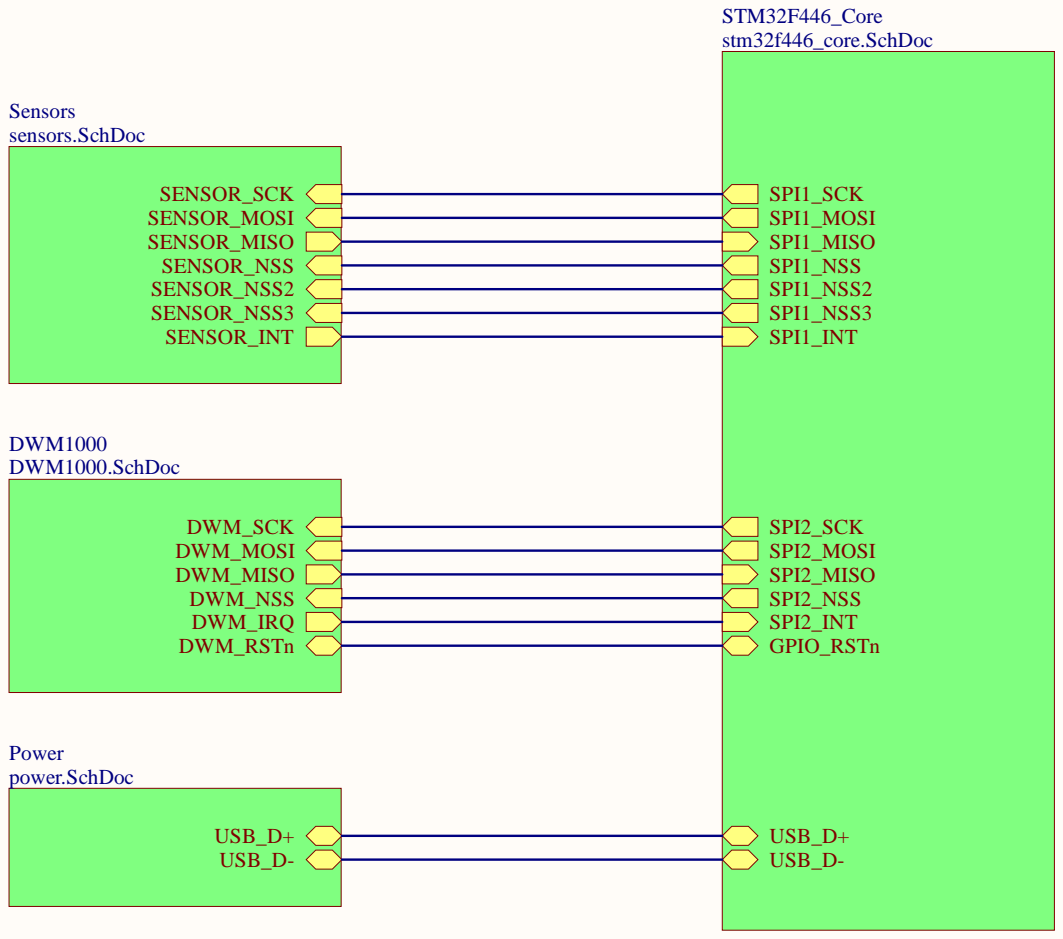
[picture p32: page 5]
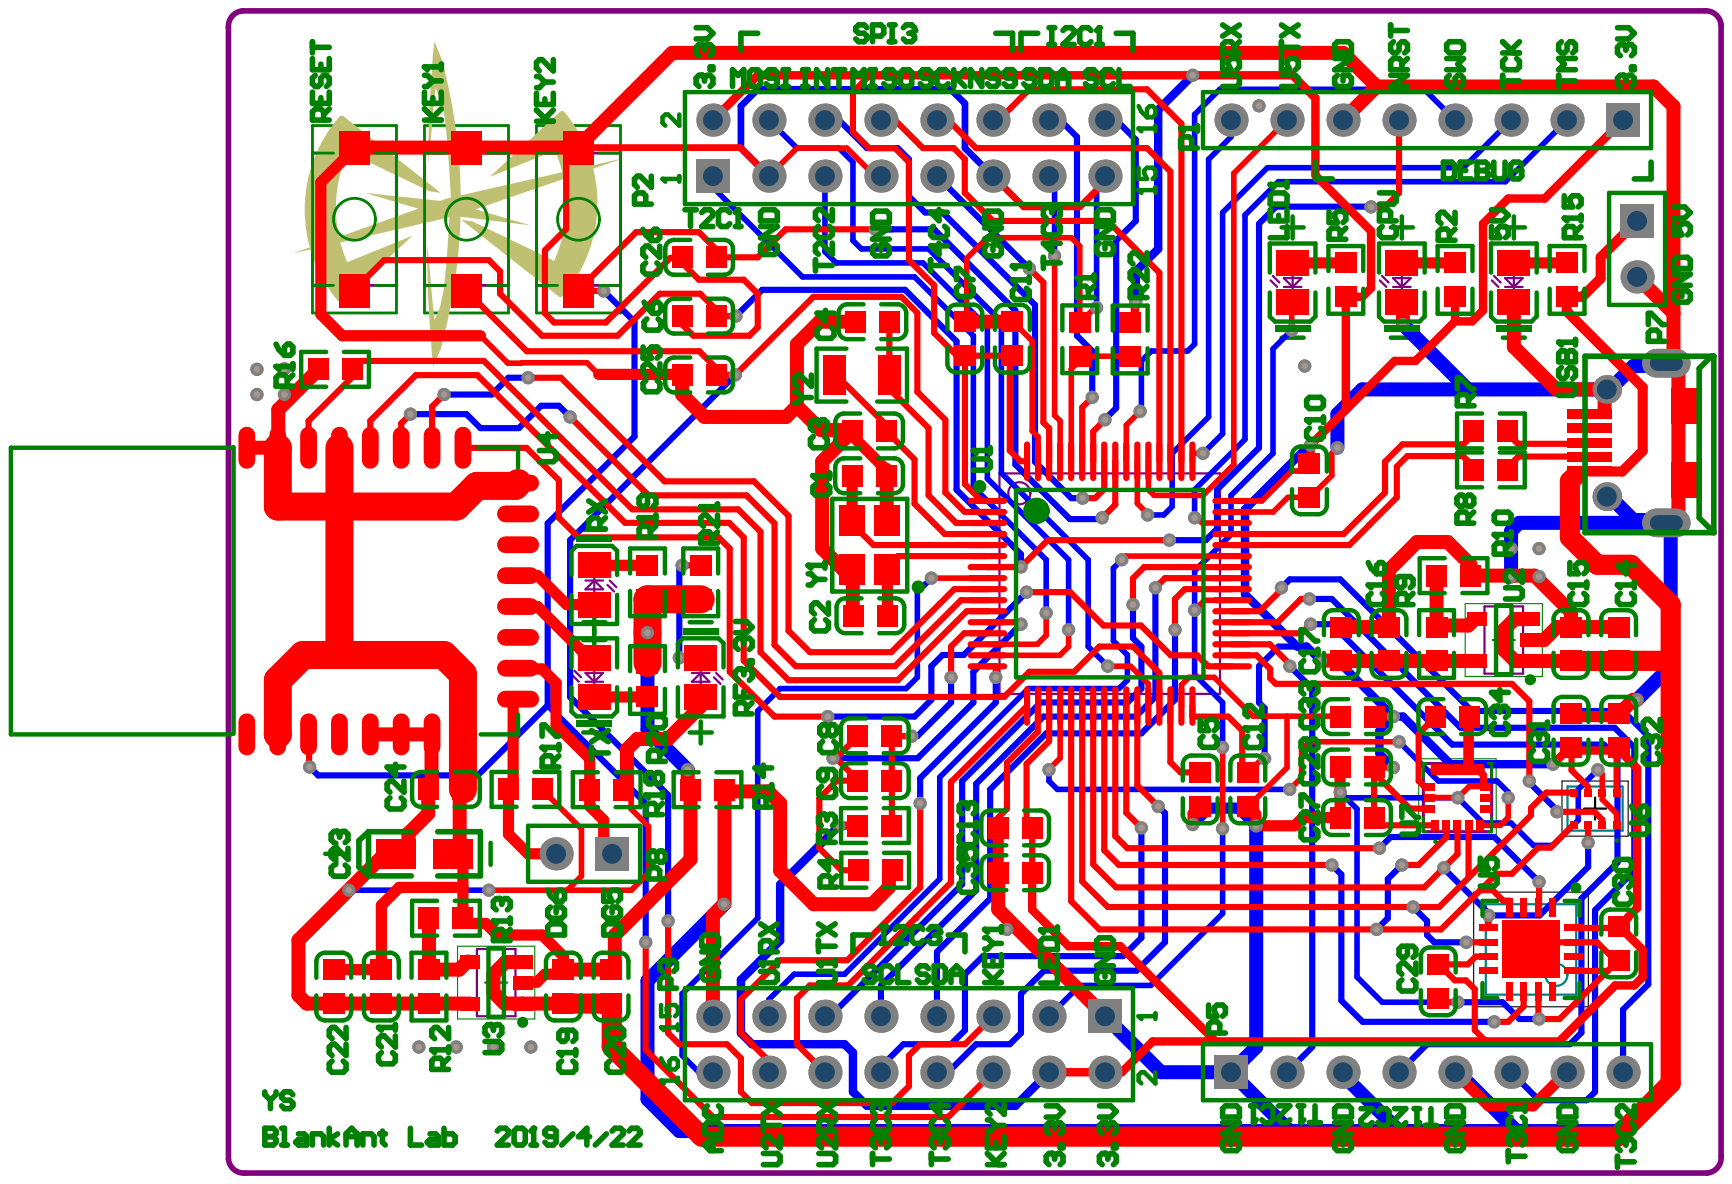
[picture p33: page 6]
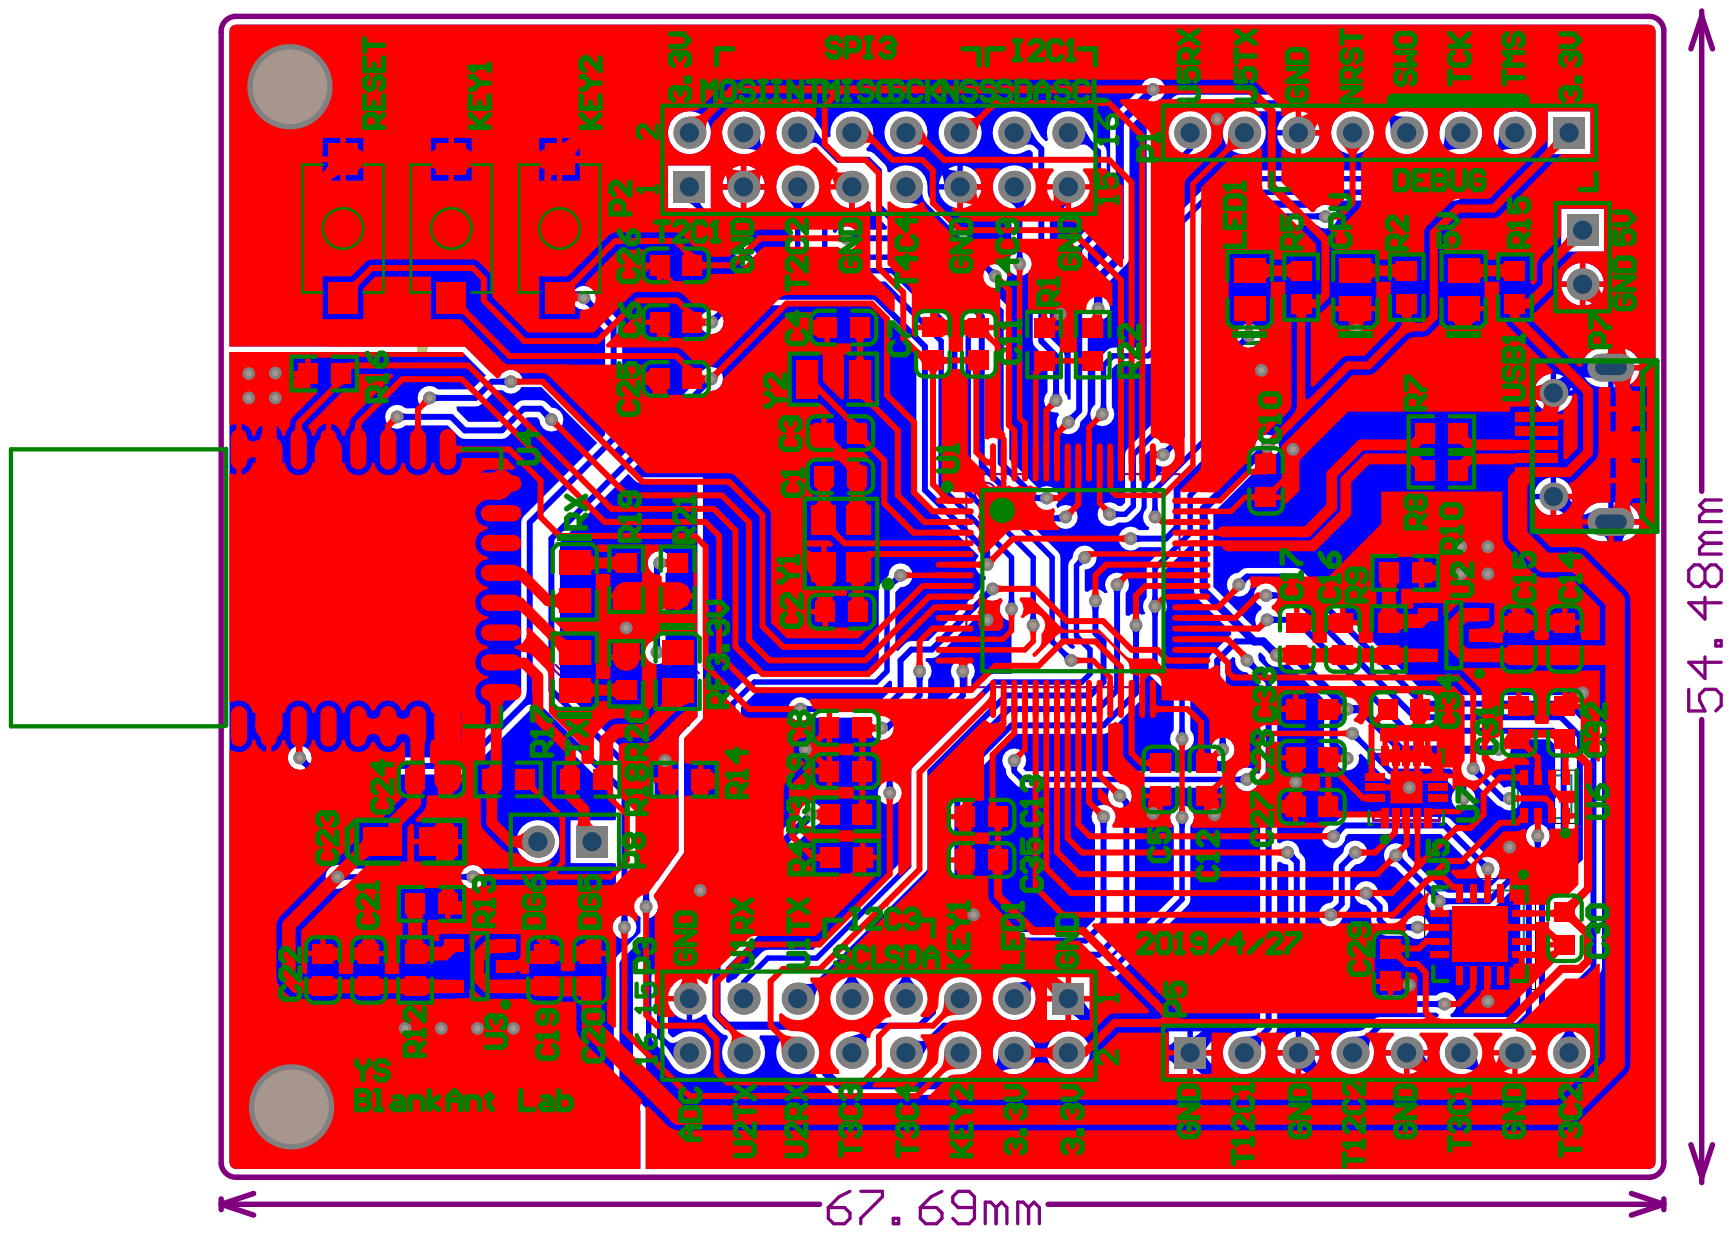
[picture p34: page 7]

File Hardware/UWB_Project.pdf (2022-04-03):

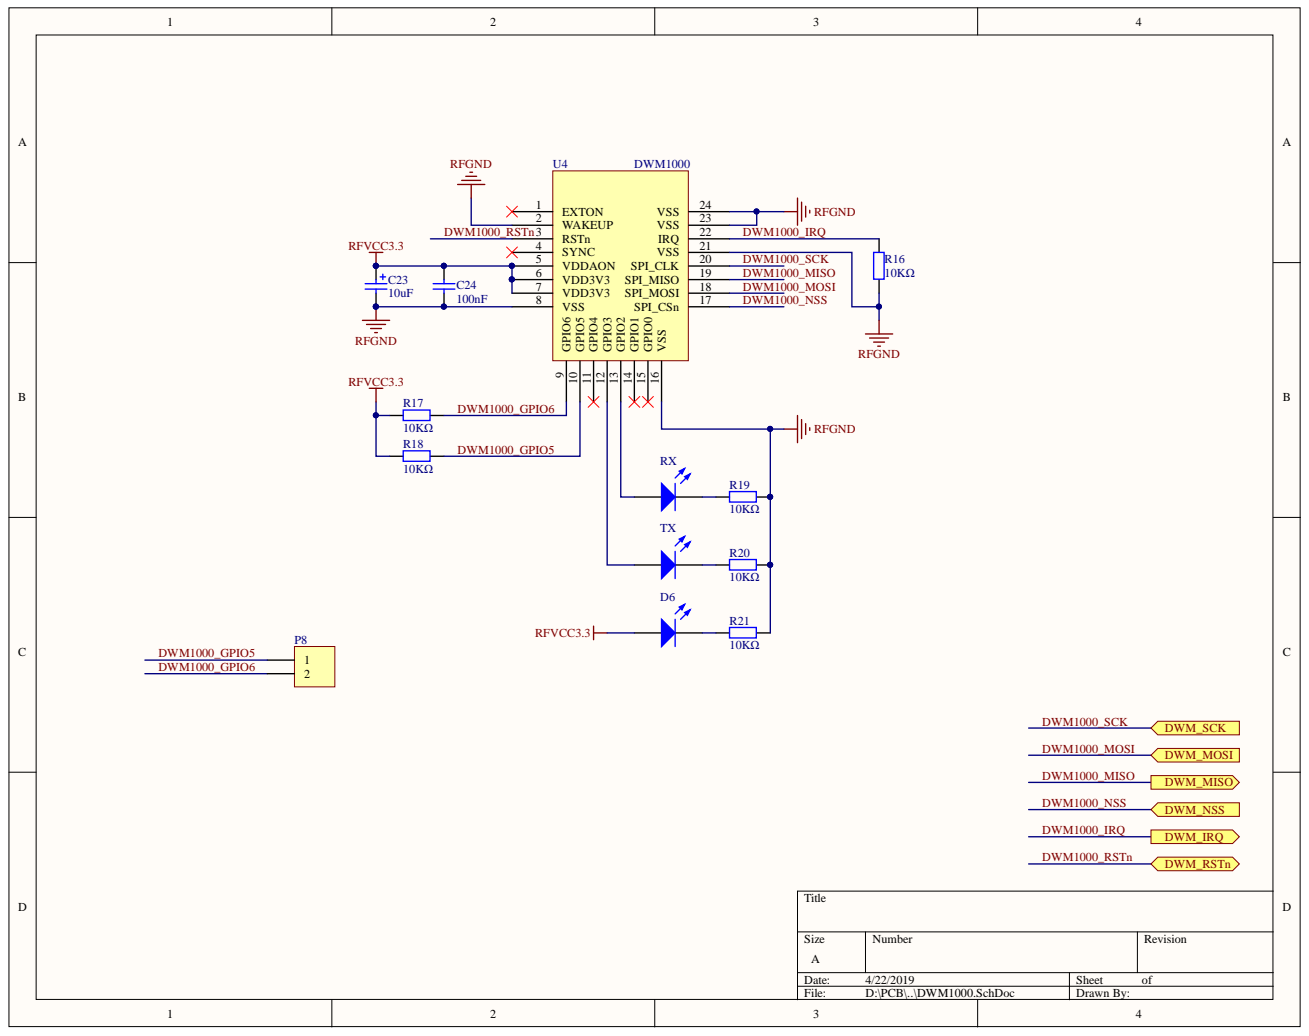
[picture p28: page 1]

VDD3V3 6

100nF | VSS 8 | | DWM1000_NSS

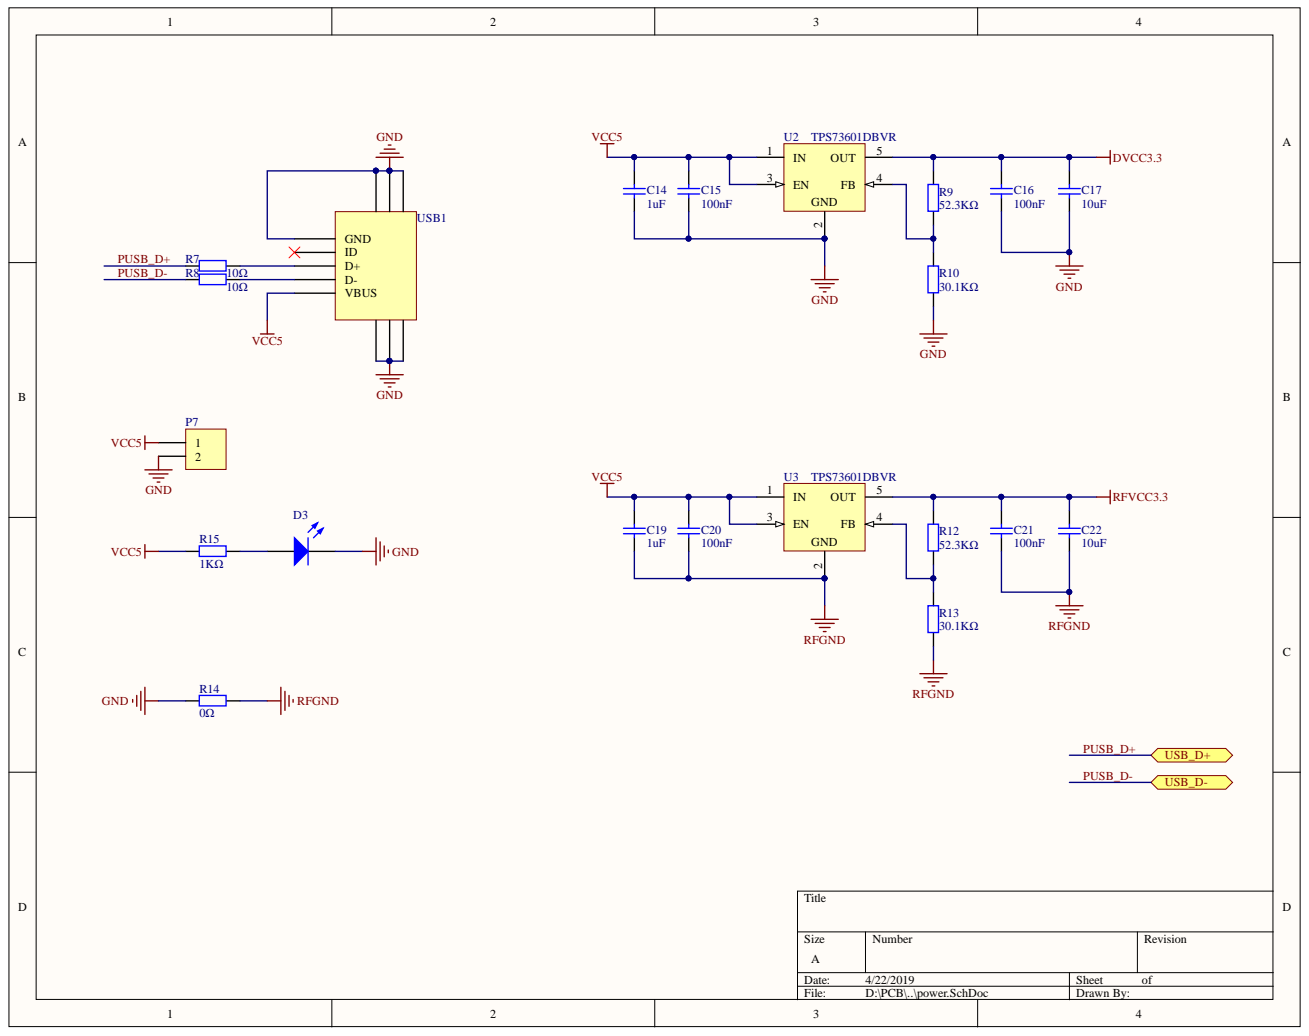
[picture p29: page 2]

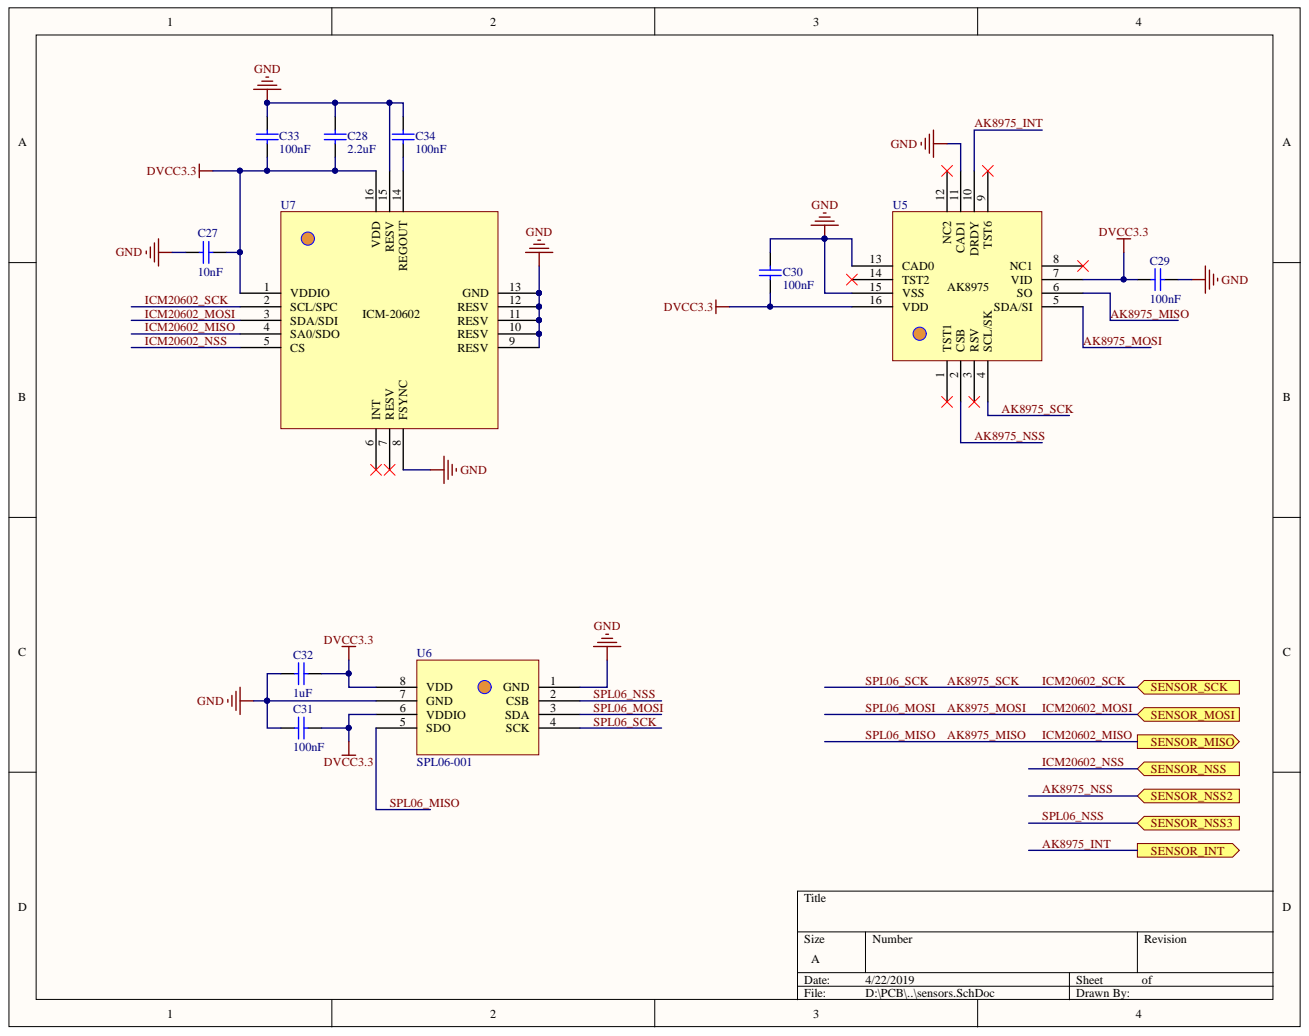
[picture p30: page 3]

SCL/SK 4 SDA/SI 5 SO 6 VID 7 NC1 8
